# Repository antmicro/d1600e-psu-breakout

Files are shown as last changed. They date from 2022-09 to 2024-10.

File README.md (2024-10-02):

# Antmicro's open source D1600E PSU Breakout Board

Copyright (c) 2022-2023 [Antmicro](https://www.antmicro.com)



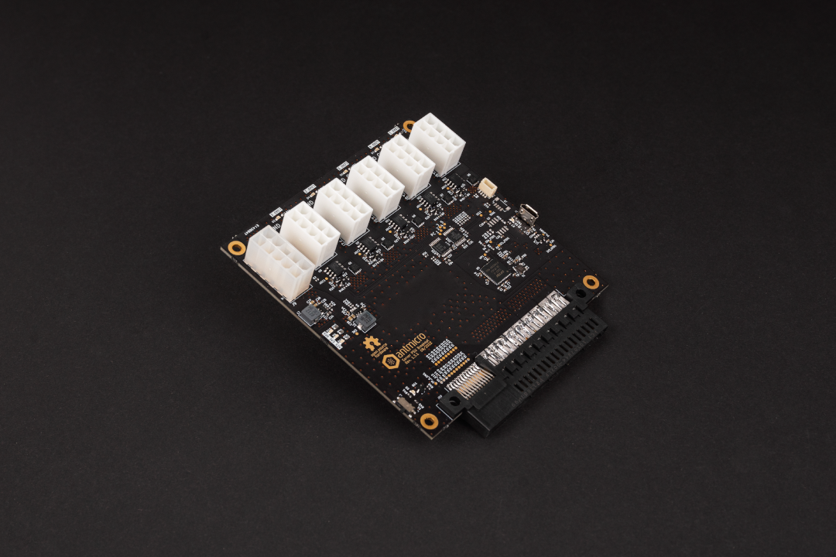
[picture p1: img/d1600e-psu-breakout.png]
Baseboard visualization


## Overview

This project contains open hardware design files for a Power Supply Unit (PSU) breakout board compatible with [Dell D1600E-S0 PSU](https://www.dell.com/en-us/work/shop/dell-power-supply-ac-1600-watt-psu-io/apd/450-ahuc/computer-chassis-components). 
The design files were prepared in KiCad.

### Project structure:

The main directory contains the KiCad design files, LICENSE and README.
The remaining files are stored in the following directories:

* ``img`` - contains graphics for this README
* ``doc`` - contains generated schematics and other documentation
* ``assets`` - contains visual assets for showcasing this design on [Open Hardware Portal](https://openhardware.antmicro.com/boards/d1600e-psu-breakout) and [Antmicro Designer](https://designer.antmicro.com/hardware/devices/d1600e-psu-breakout).

## Key features

* 5x power output channels providing 12V over 8-pin PCI Express type (Molex/39288080) sockets
* Up to 220W per single 12V power output channel
* Output current measurement implemented with [Ti/TMCS1100A2QDRQ1](https://www.ti.com/lit/ds/symlink/tmcs1100-q1.pdf) Hall sensors and 12-bit [Ti/ADS7828E](https://www.ti.com/lit/ds/symlink/ads7828.pdf) ADC accessible over I2C
* Power-cycling for each channel implemented with power MOSFETS driven from [Ti/TCA9534](https://www.ti.com/lit/ds/symlink/tca9534.pdf) GPIO expander accessible over I2C 
* I2C bus for current measurements and power cycling is opto-coupled with [FTDI/FT4232H-56Q](https://www.ftdichip.com/Support/Documents/DataSheets/ICs/DS_FT4232H.pdf) with USB exposed towards an external host
* Auxilary connector (Molex/39281103) exposing 5.0V,3.3V,12V for connecting external peripherals

## License

This project is published under the [Apache-2.0](LICENSE) license.

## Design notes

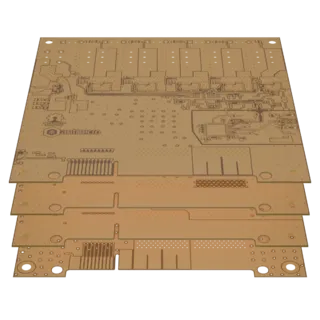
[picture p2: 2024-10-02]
assets/previews/layer1_thumbnail.webp

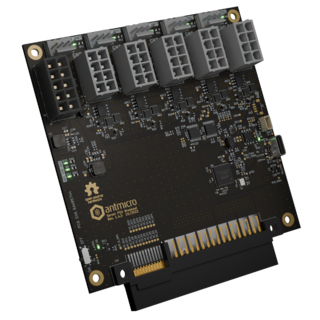
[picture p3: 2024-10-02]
assets/previews/leftT_thumbnail.png

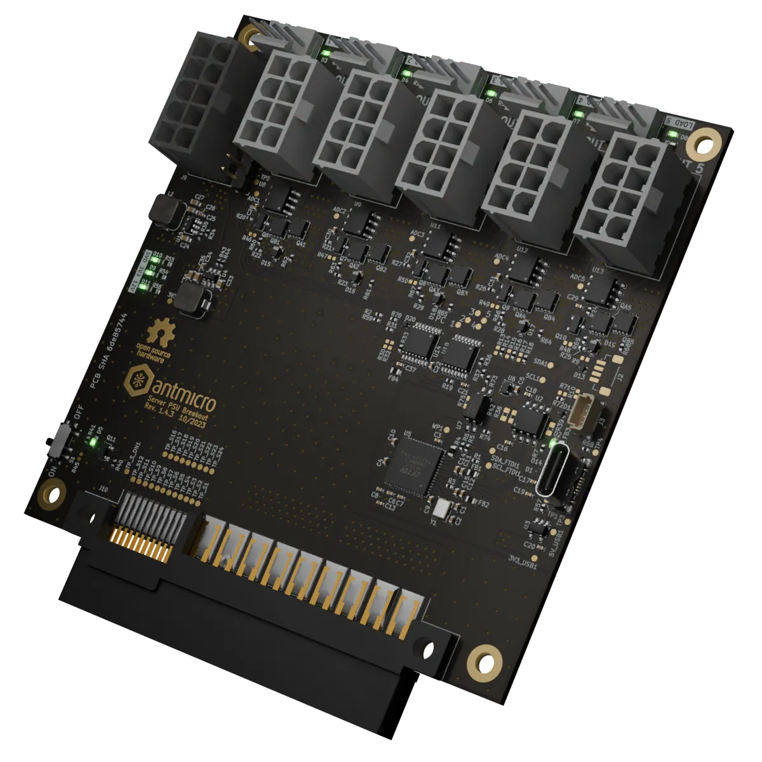
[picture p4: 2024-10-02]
assets/previews/rightT.webp

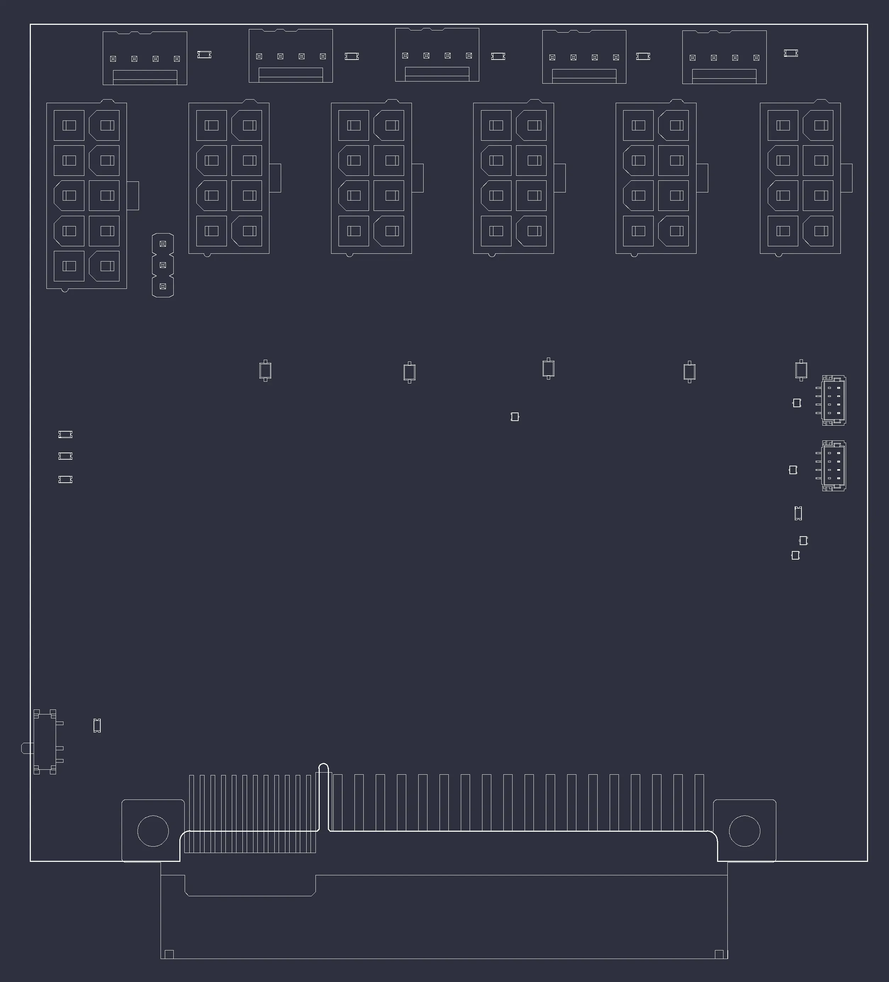
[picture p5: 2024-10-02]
assets/wireframe/wireframe_descriptions_top.webp

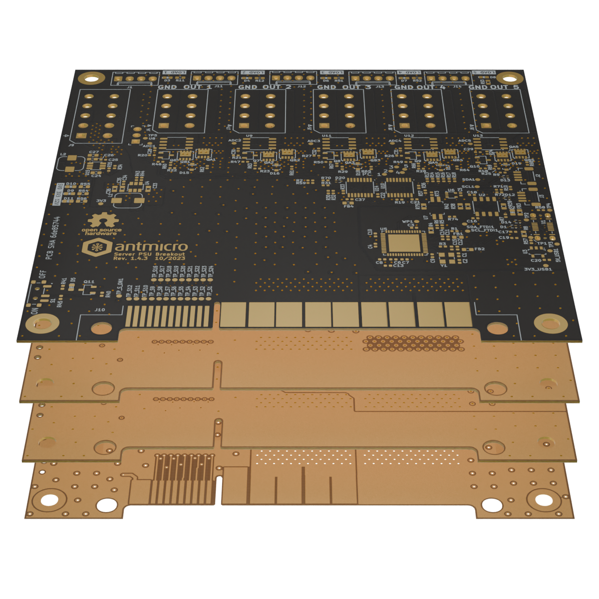
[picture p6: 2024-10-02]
assets/previews/stackup.png

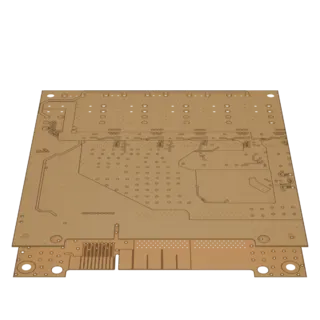
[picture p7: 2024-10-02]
assets/previews/layer3_thumbnail.webp

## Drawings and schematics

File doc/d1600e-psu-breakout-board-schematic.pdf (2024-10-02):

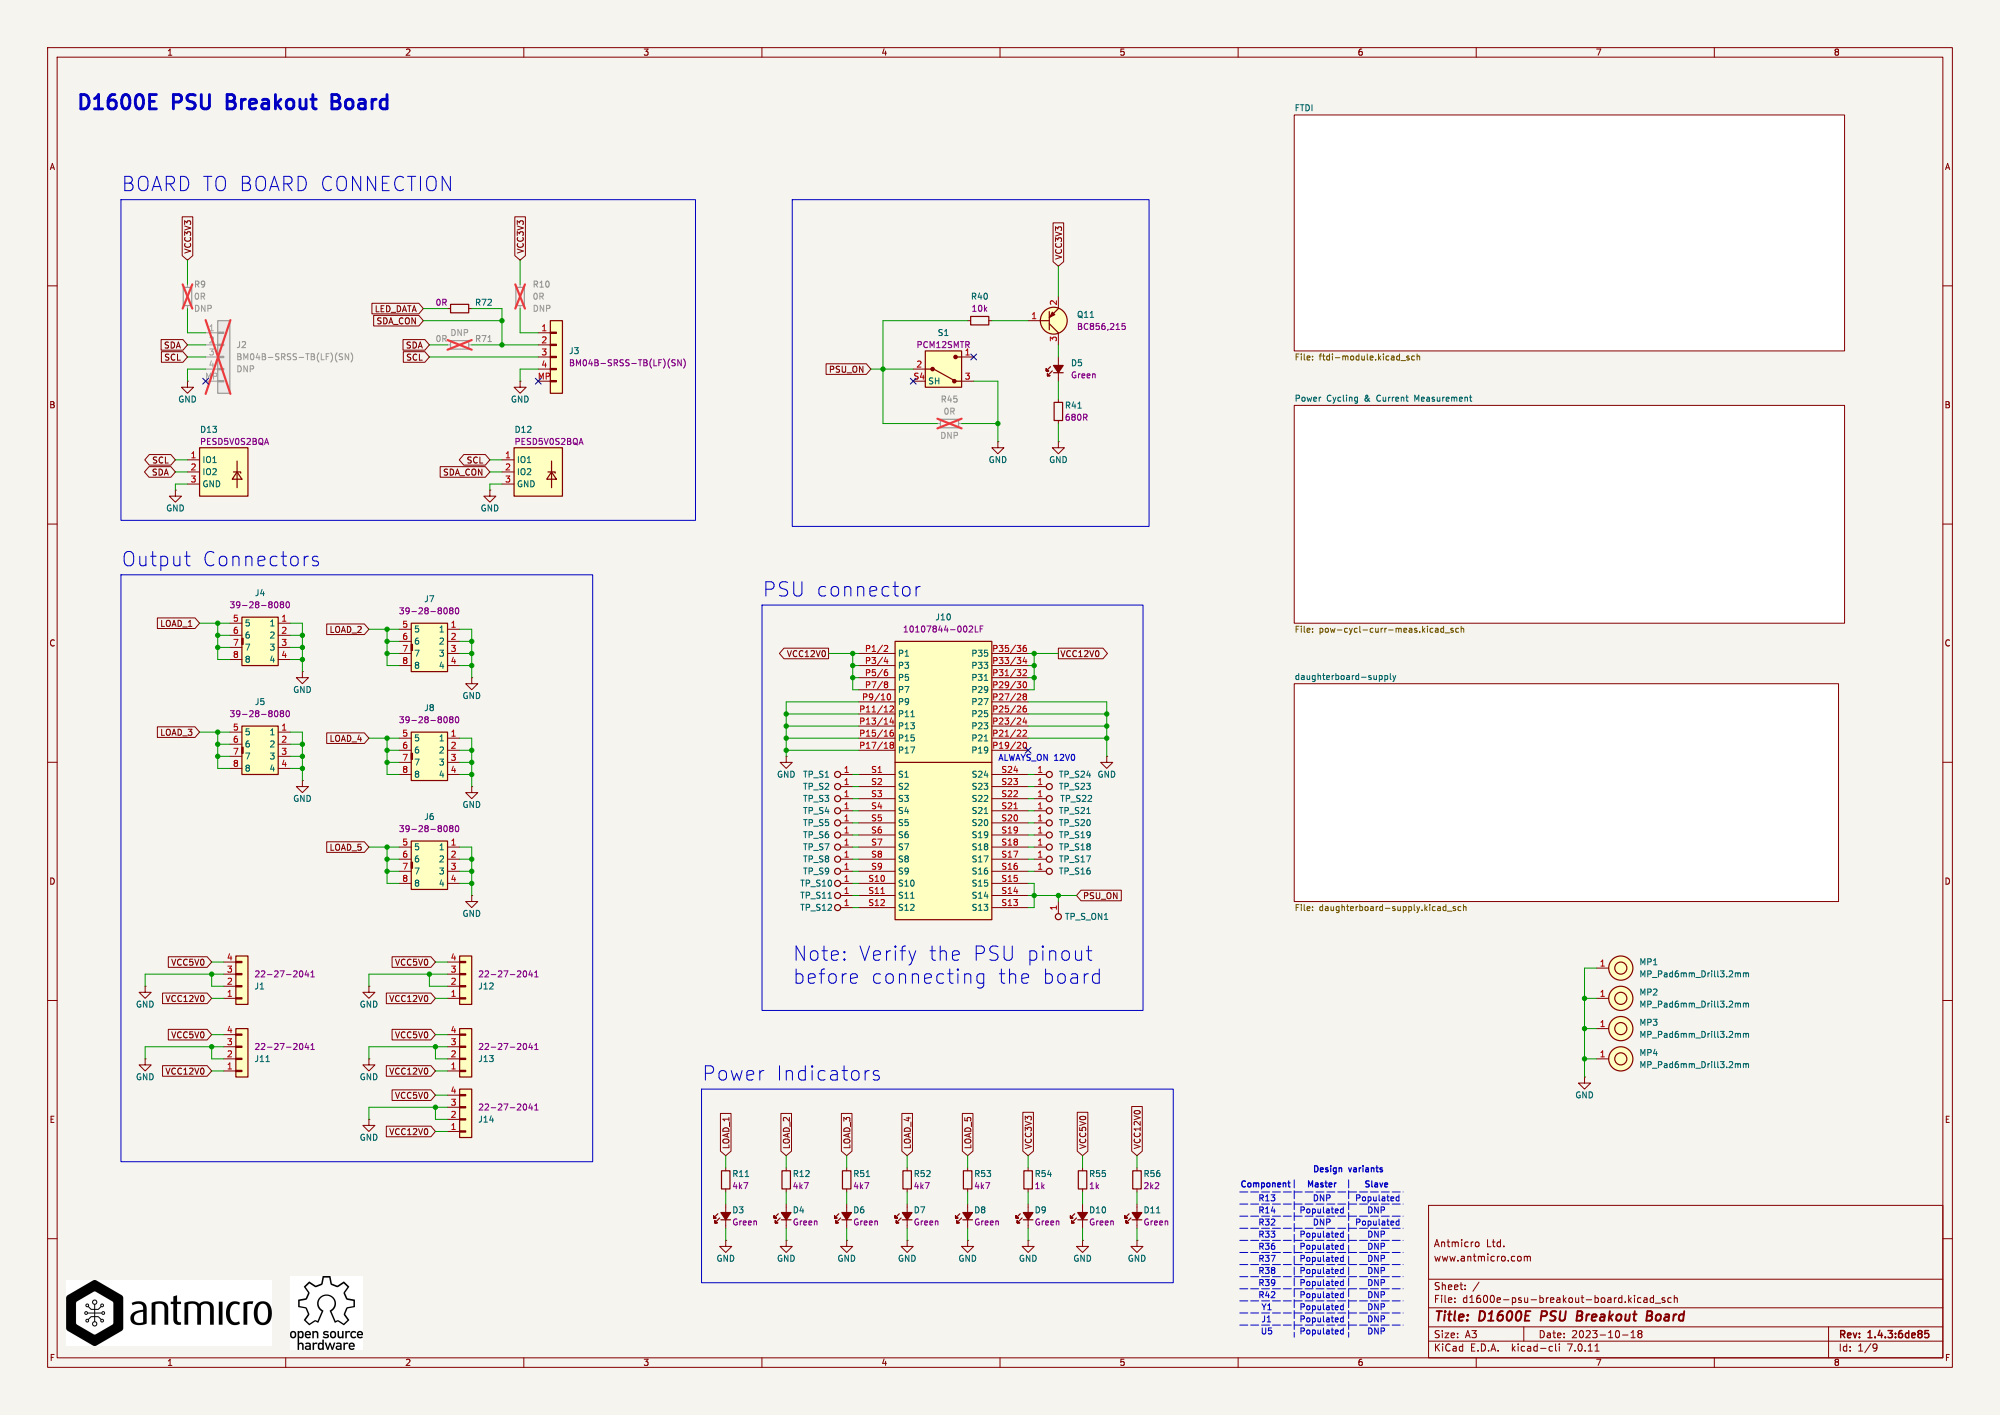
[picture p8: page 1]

FTDI File: ftdi-module.kicad_sch Power Cycling & Current Measurement File: pow-cycl-curr-meas.kicad_sch R41

ALWAYS_ON 12V0 BOARD TO BOARD CONNECTION

daughterboard-supply File: daughterboard-supply.kicad_sch

Note: Verify the PSU pinout

File: d1600e-psu-breakout-board.kicad_sch Sheet: / www.antmicro.com

Id: 1/9 Title: D1600E PSU Breakout Board

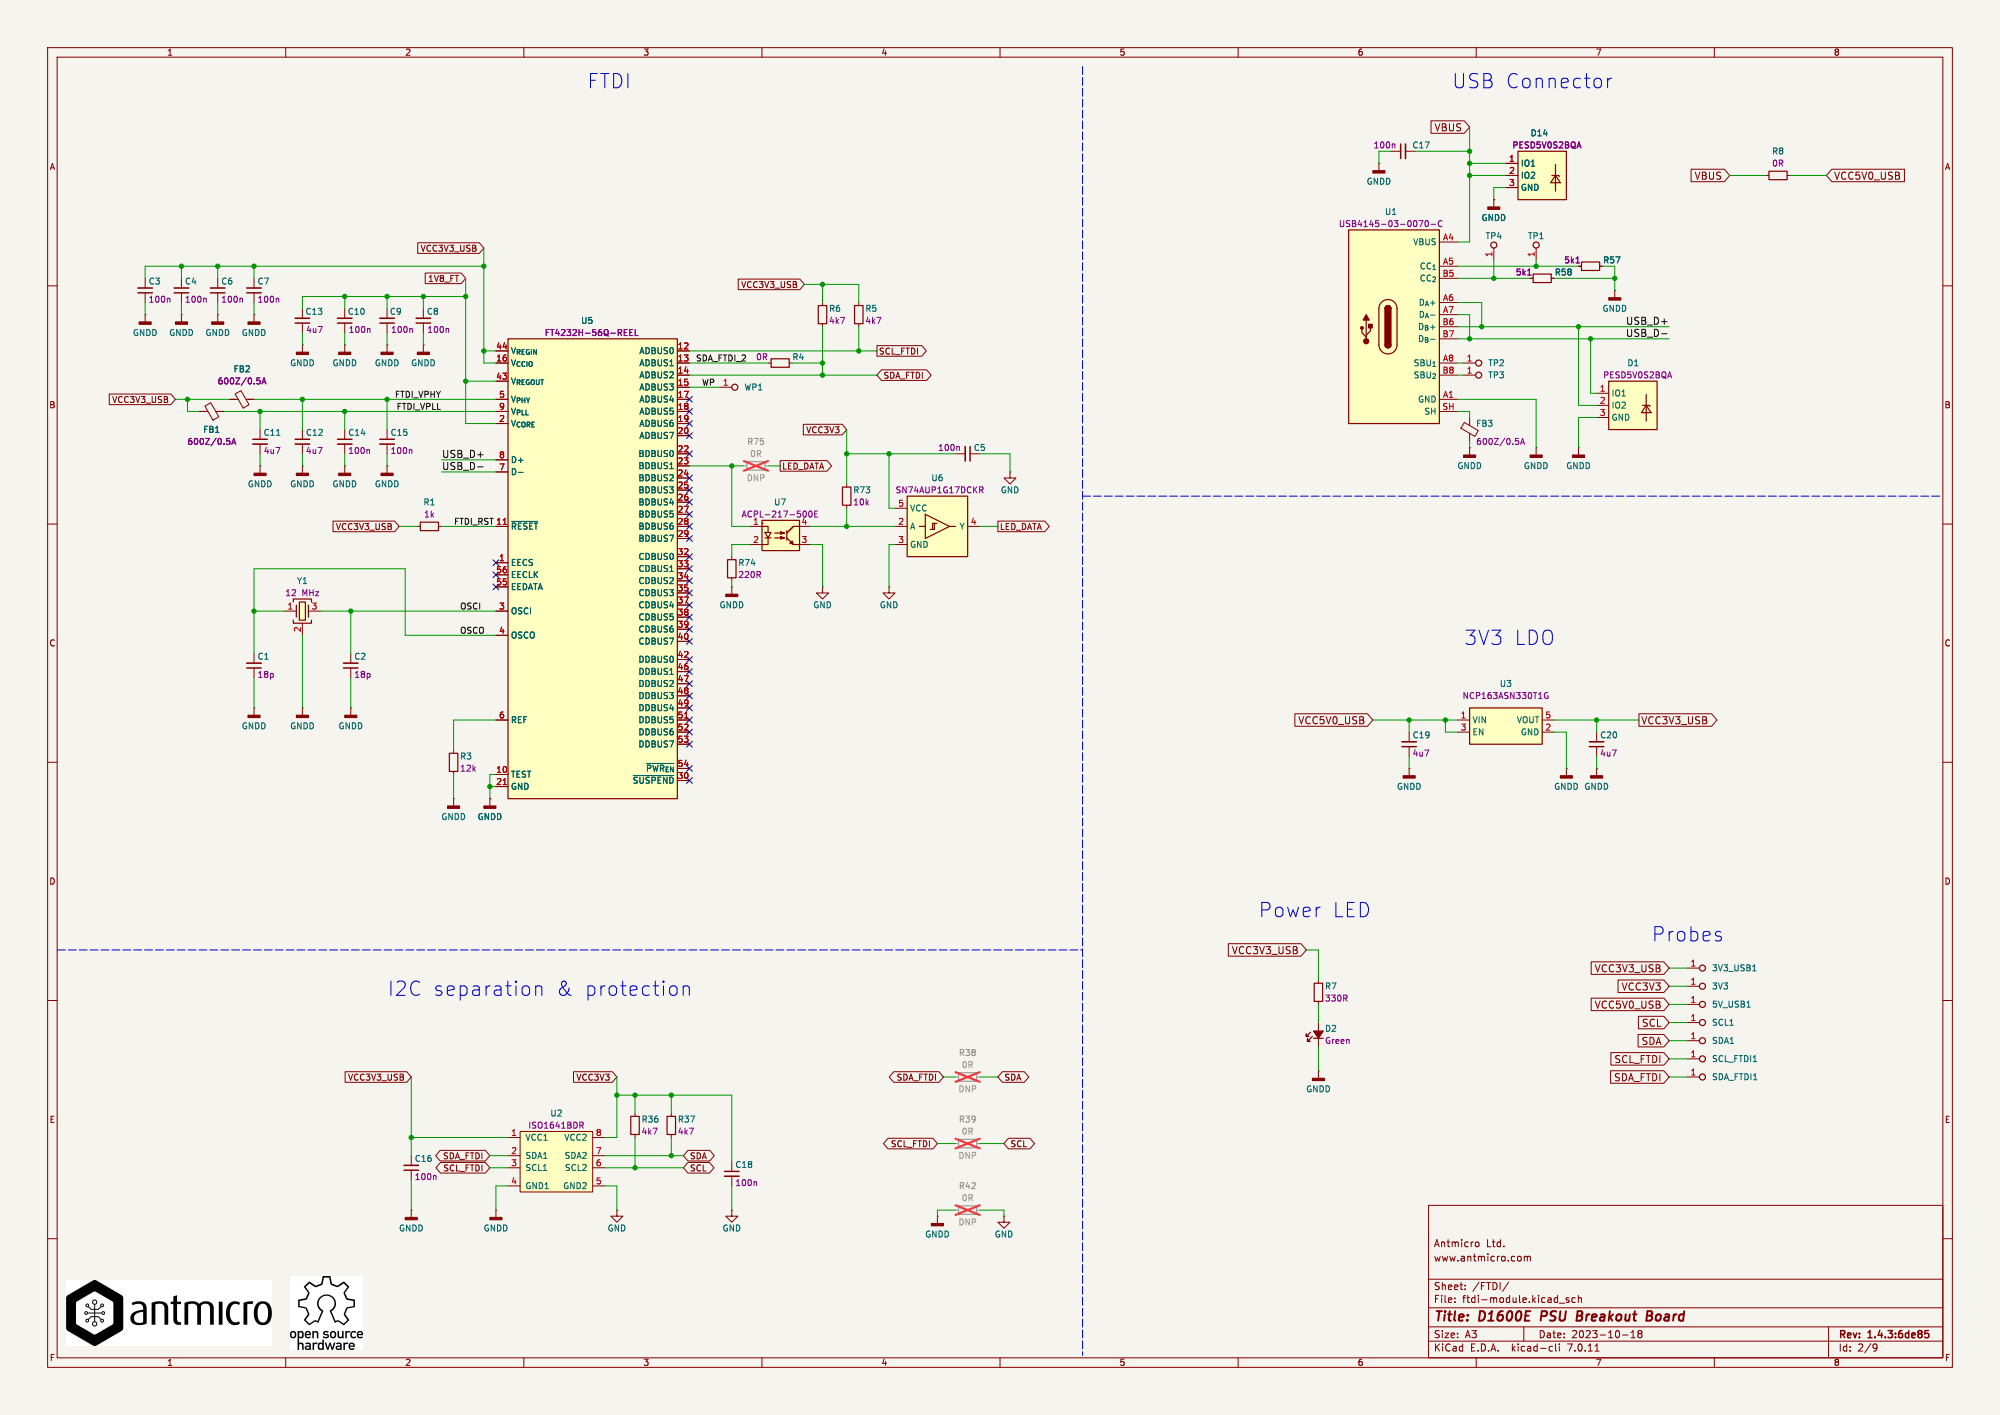
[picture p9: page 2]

File: ftdi-module.kicad_sch Sheet: /FTDI/ www.antmicro.com

Id: 2/9 Title: D1600E PSU Breakout Board

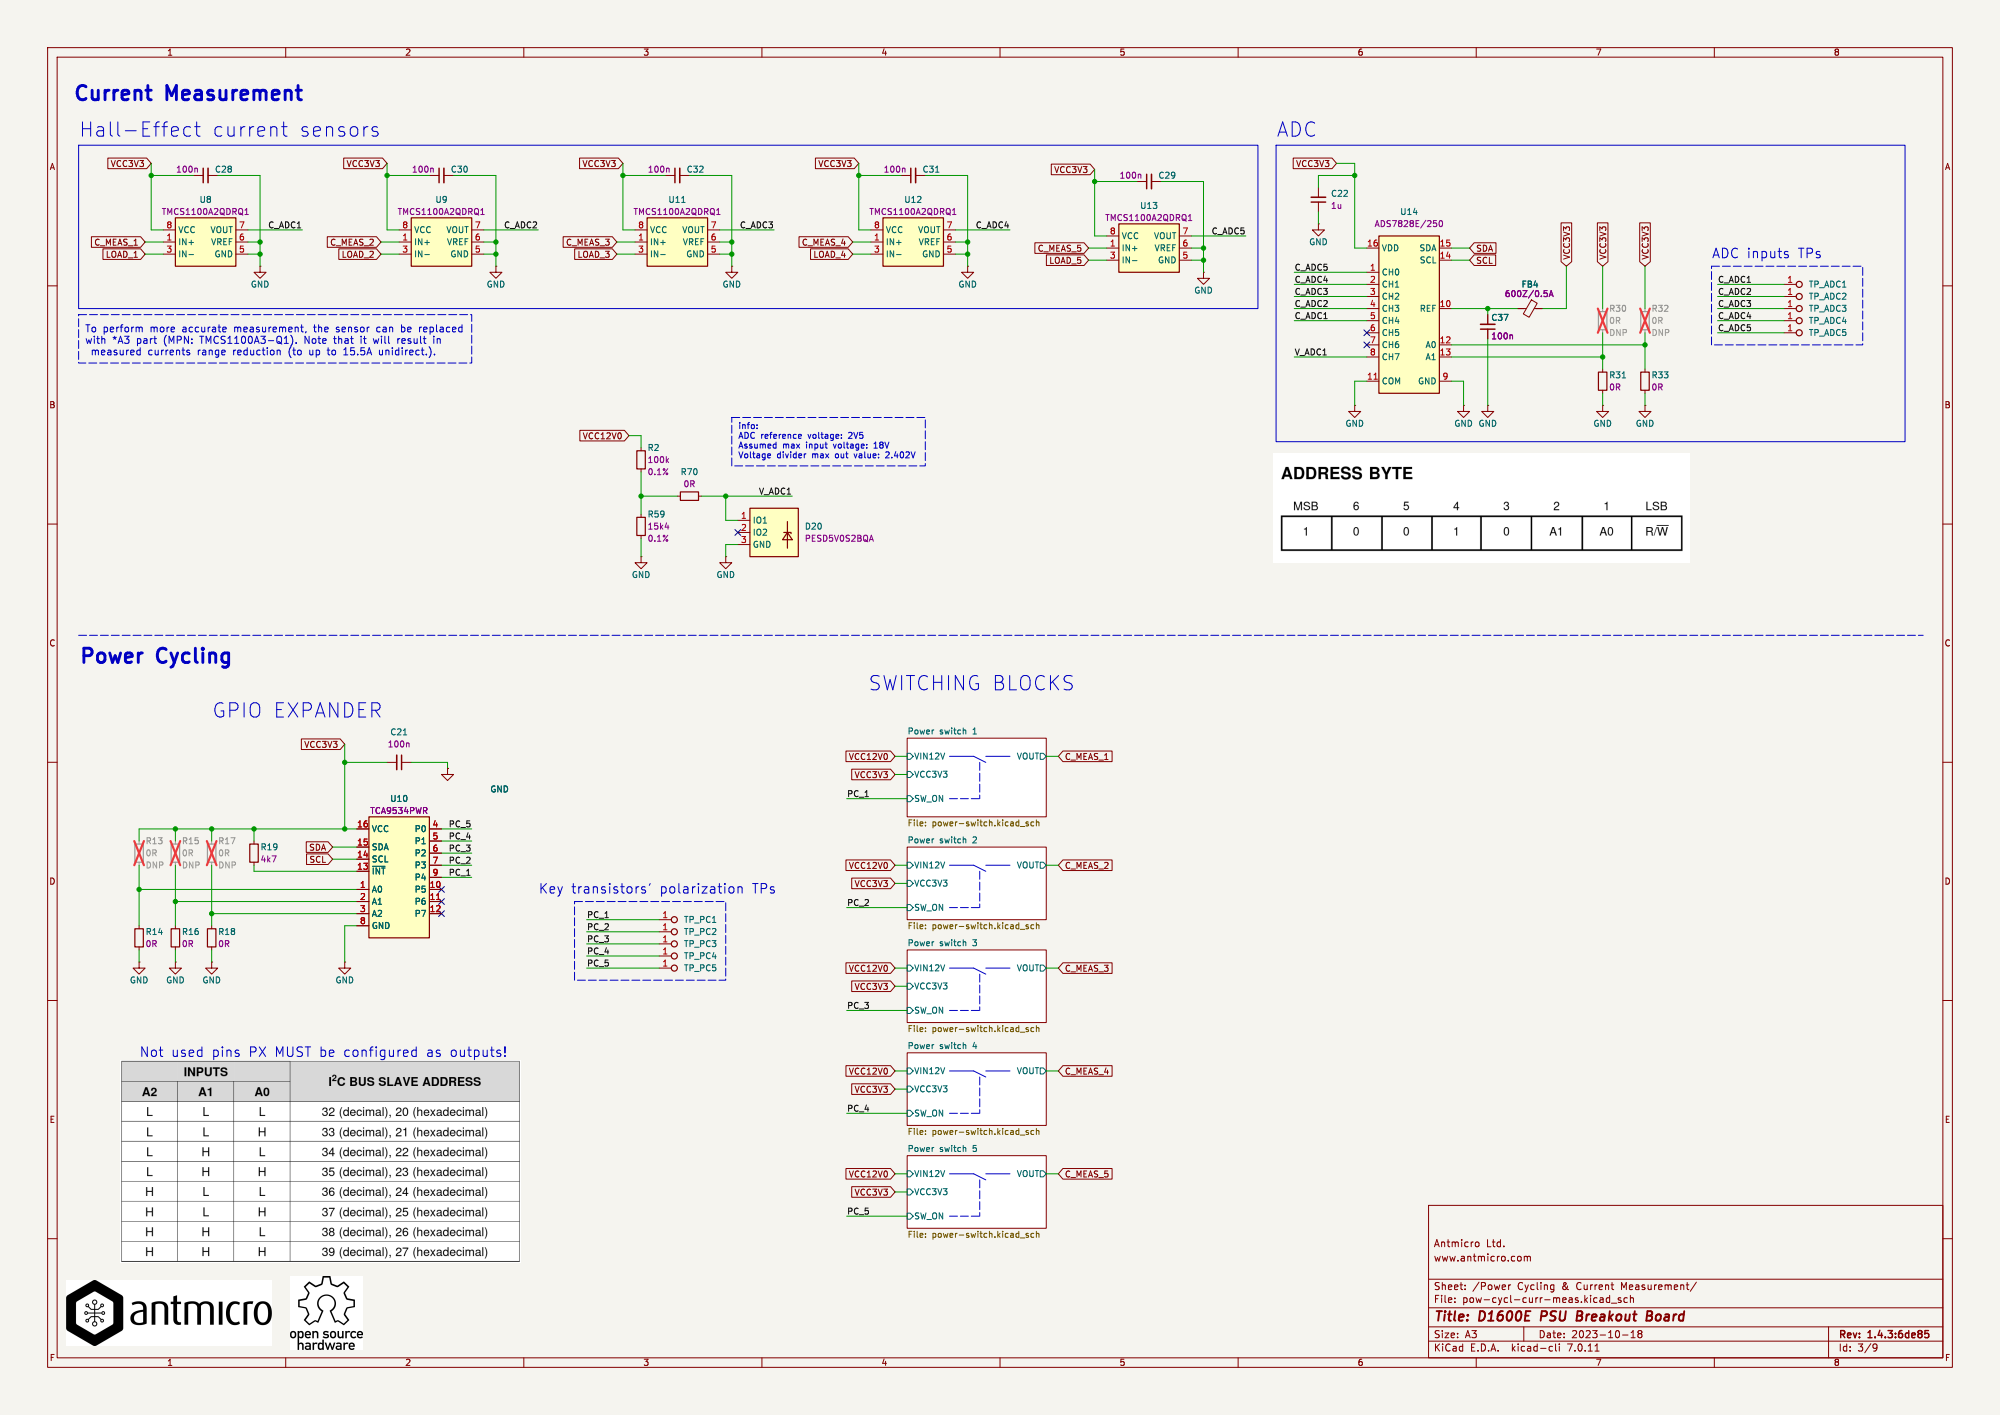
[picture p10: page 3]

Id: 3/9 Title: D1600E PSU Breakout Board

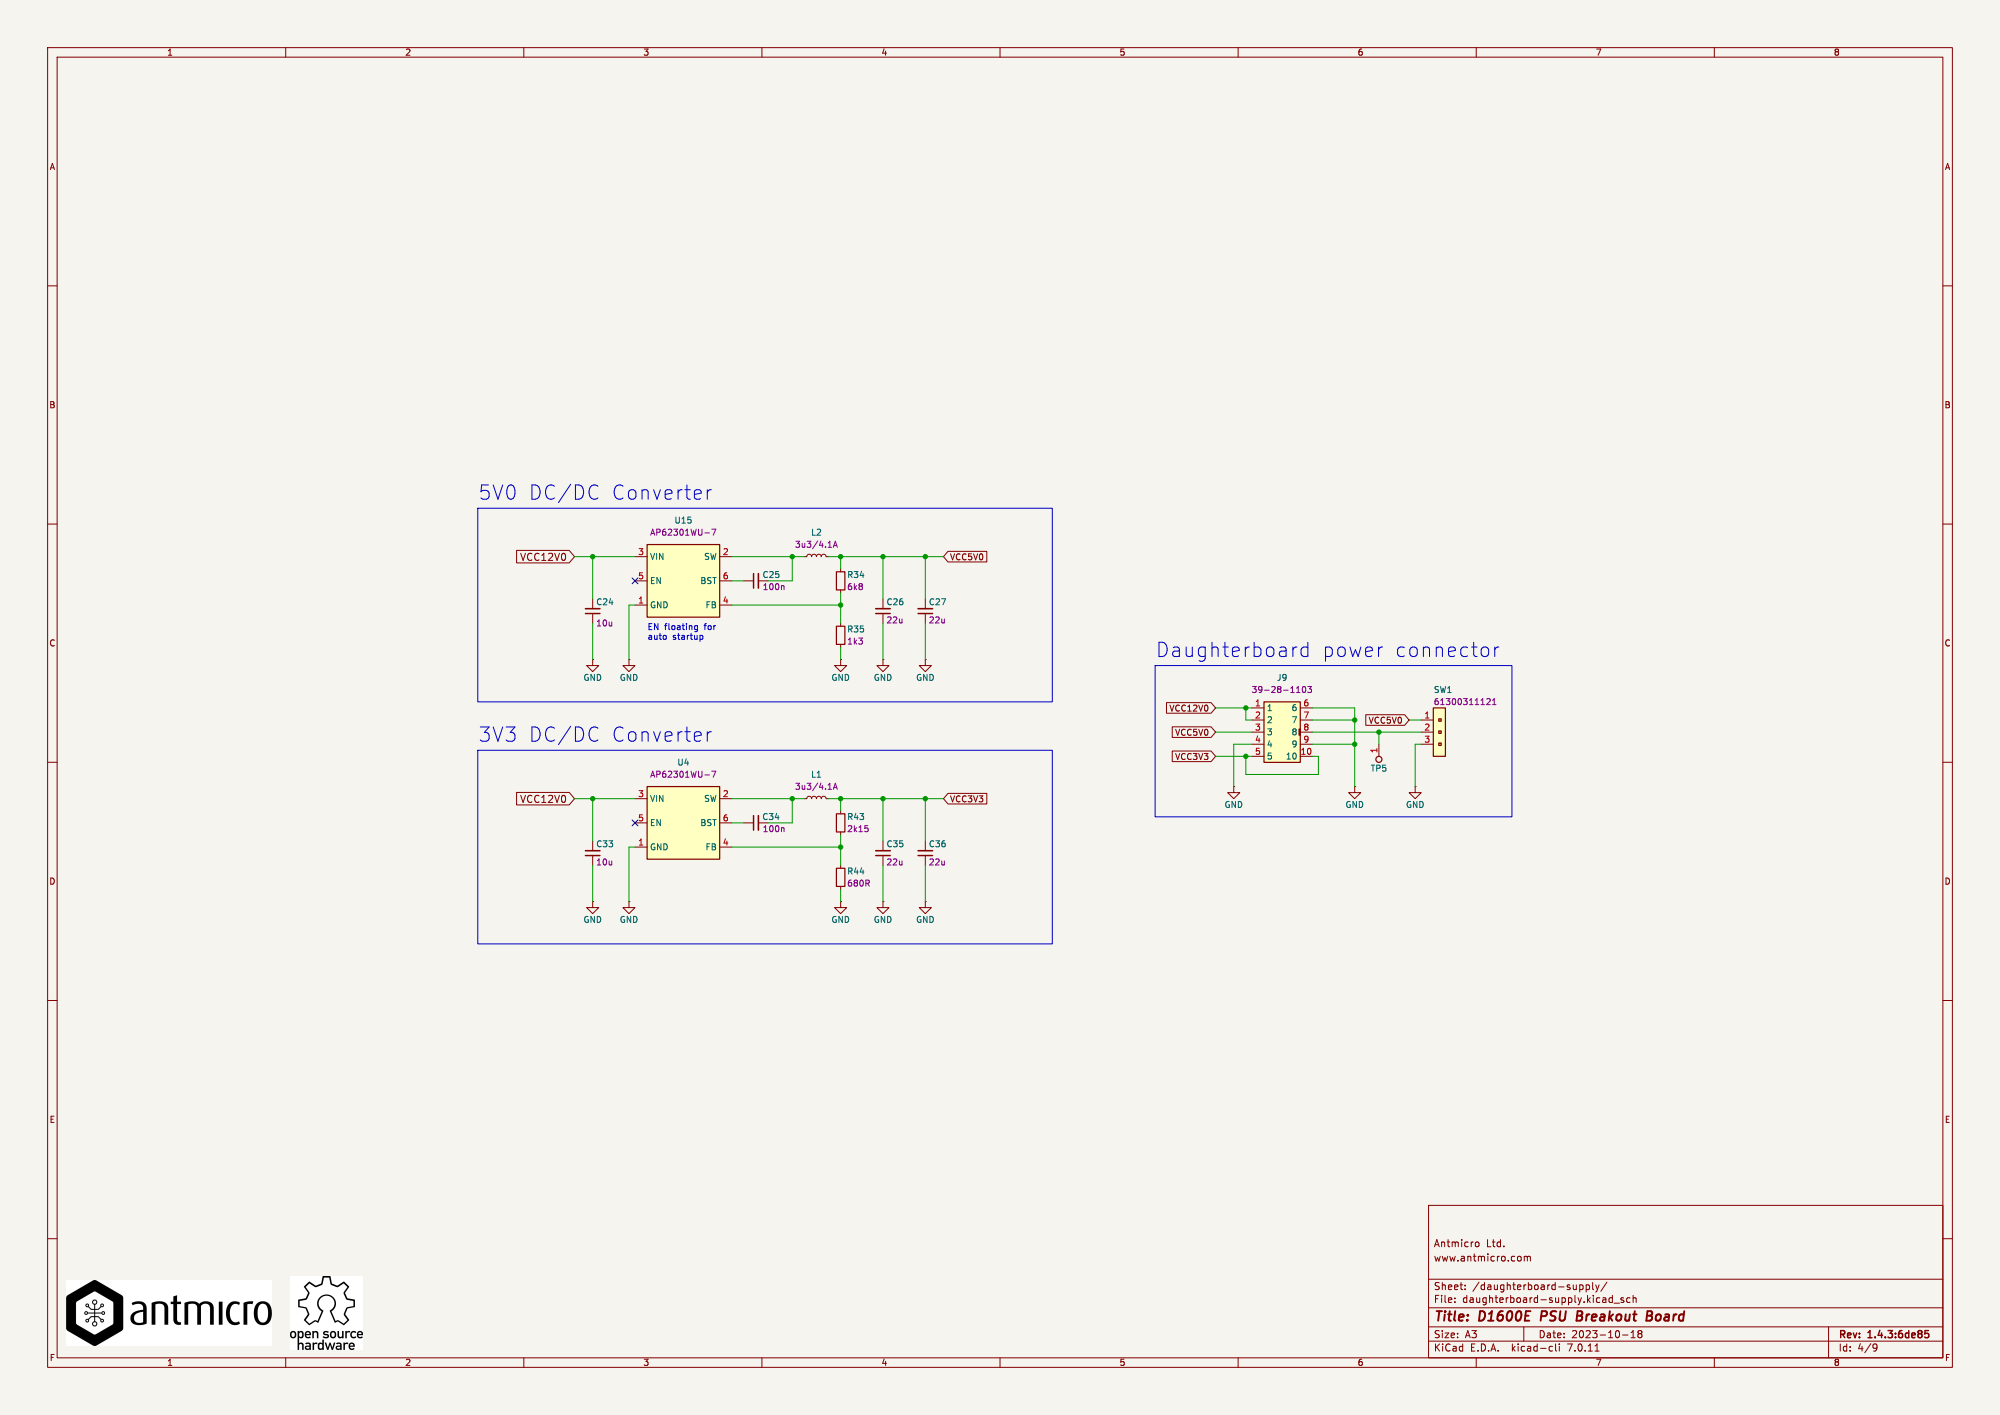
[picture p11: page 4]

File: daughterboard-supply.kicad_sch Sheet: /daughterboard-supply/ www.antmicro.com

Id: 4/9 Title: D1600E PSU Breakout Board

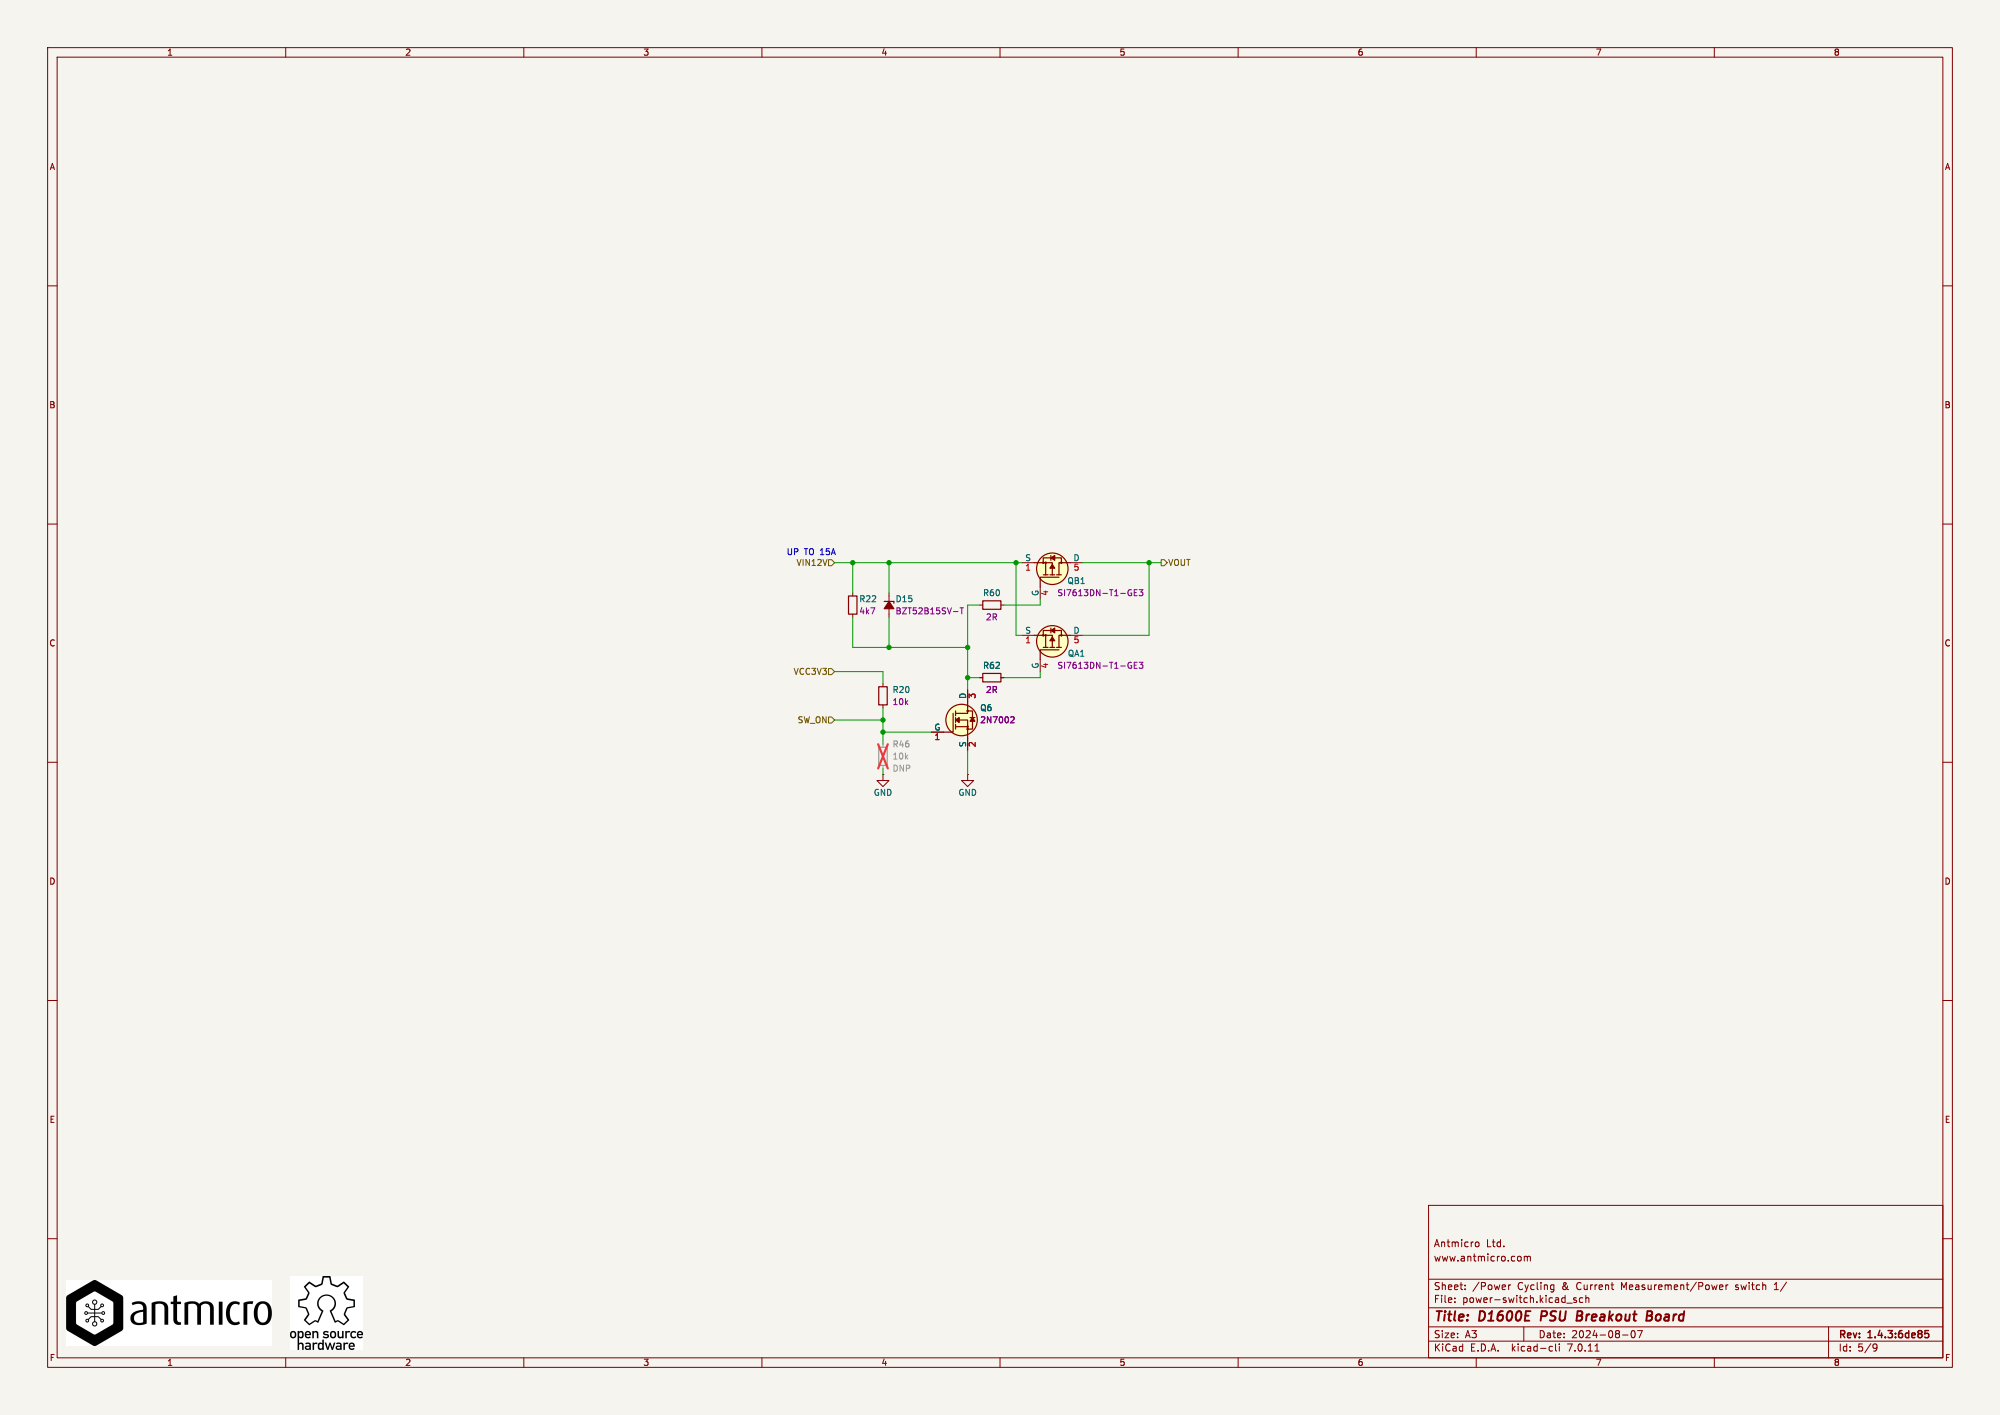
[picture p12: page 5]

Id: 5/9 Title: D1600E PSU Breakout Board

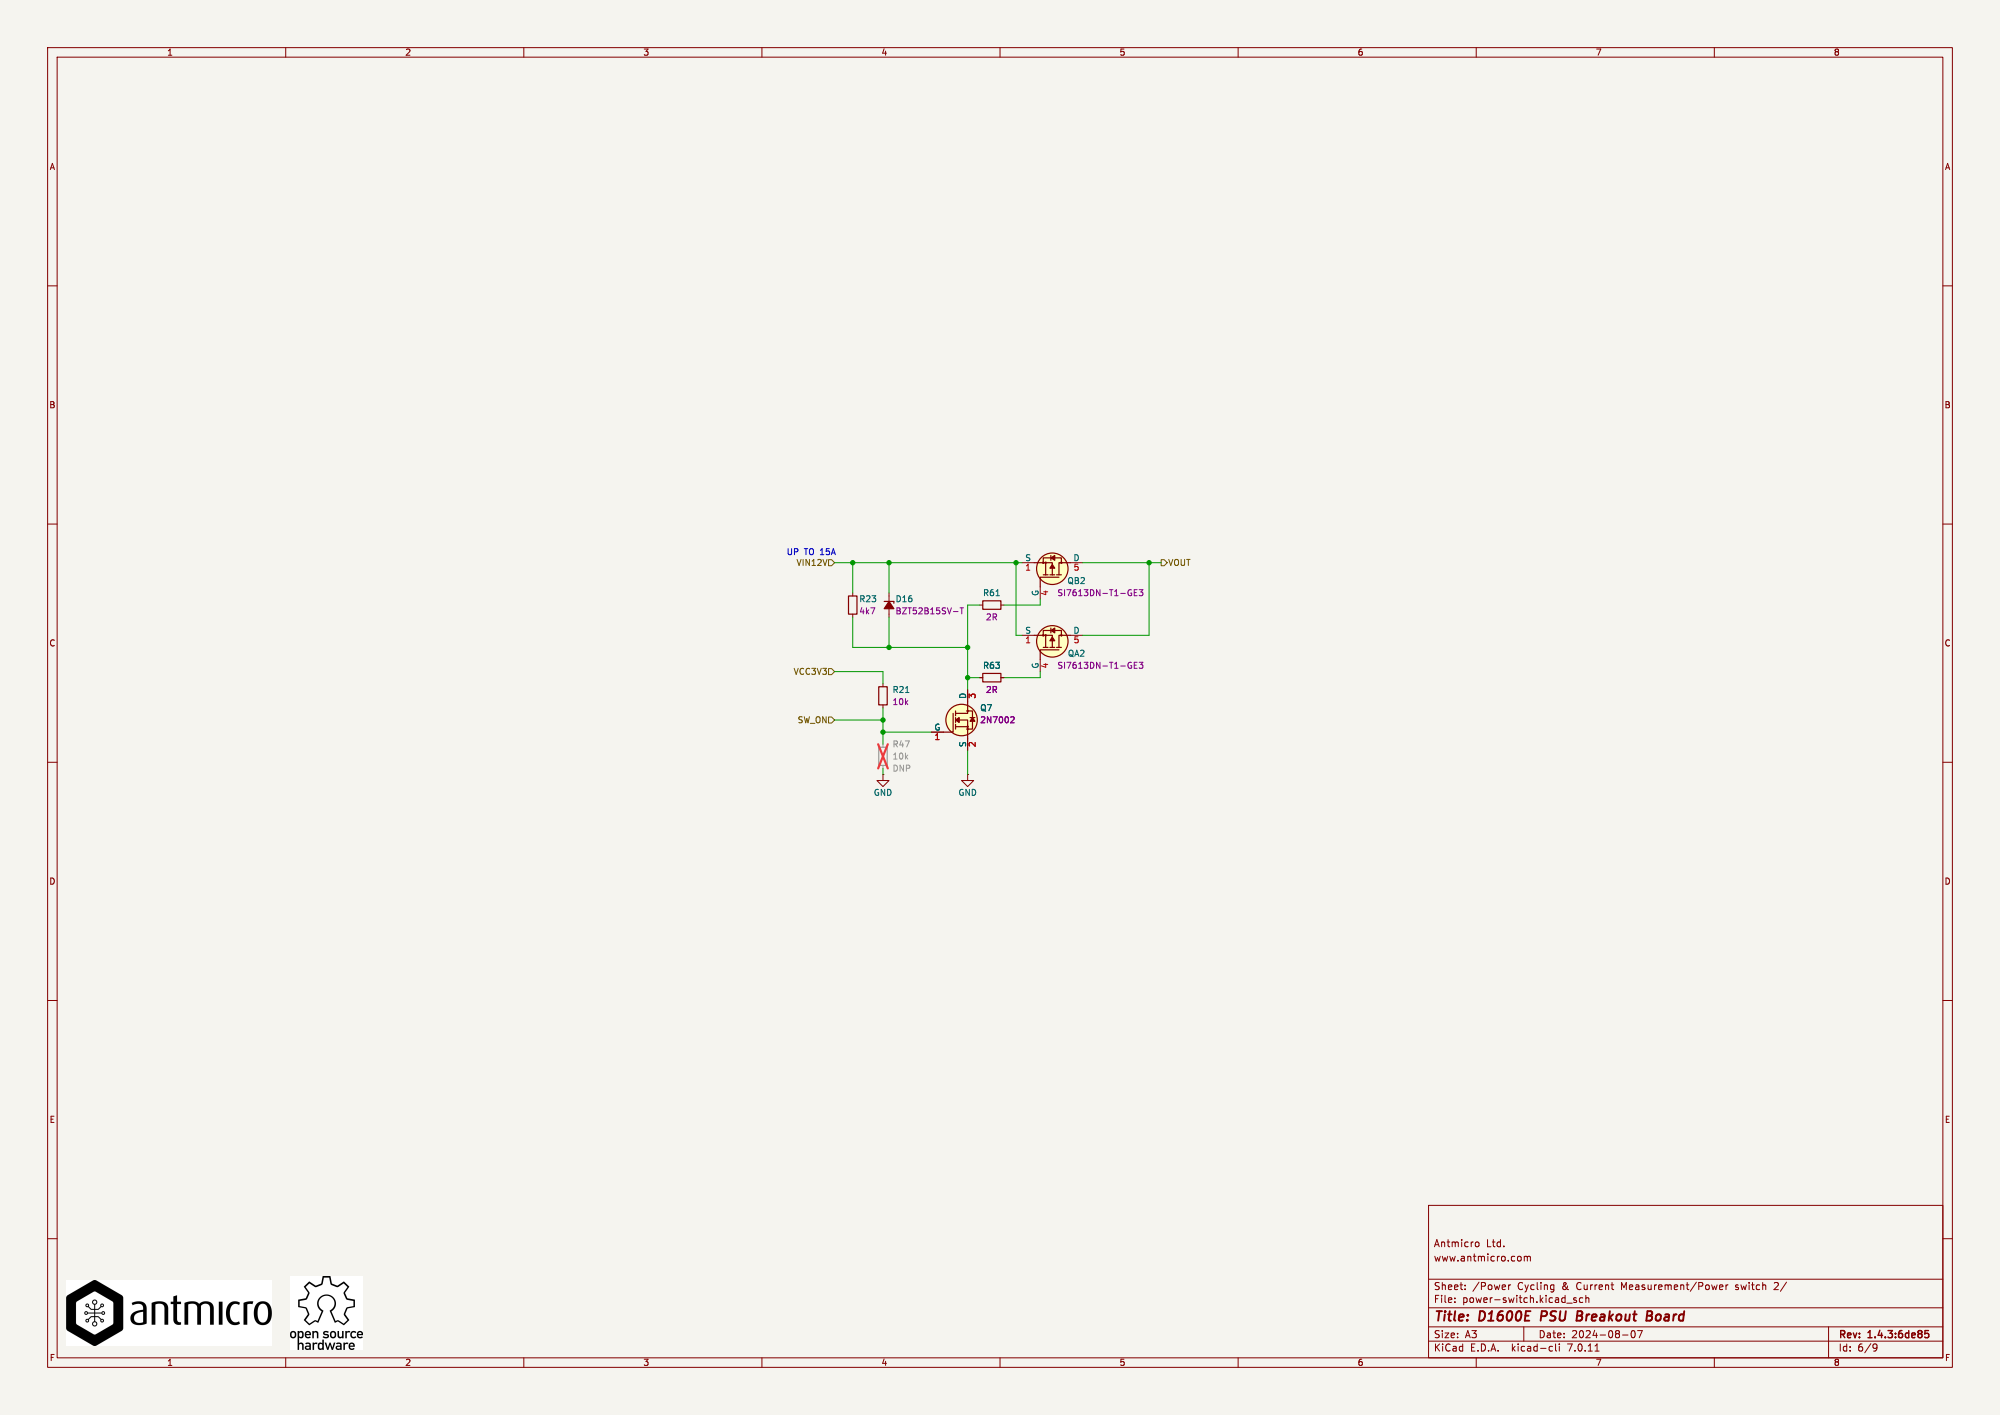
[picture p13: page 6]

Id: 6/9 Title: D1600E PSU Breakout Board

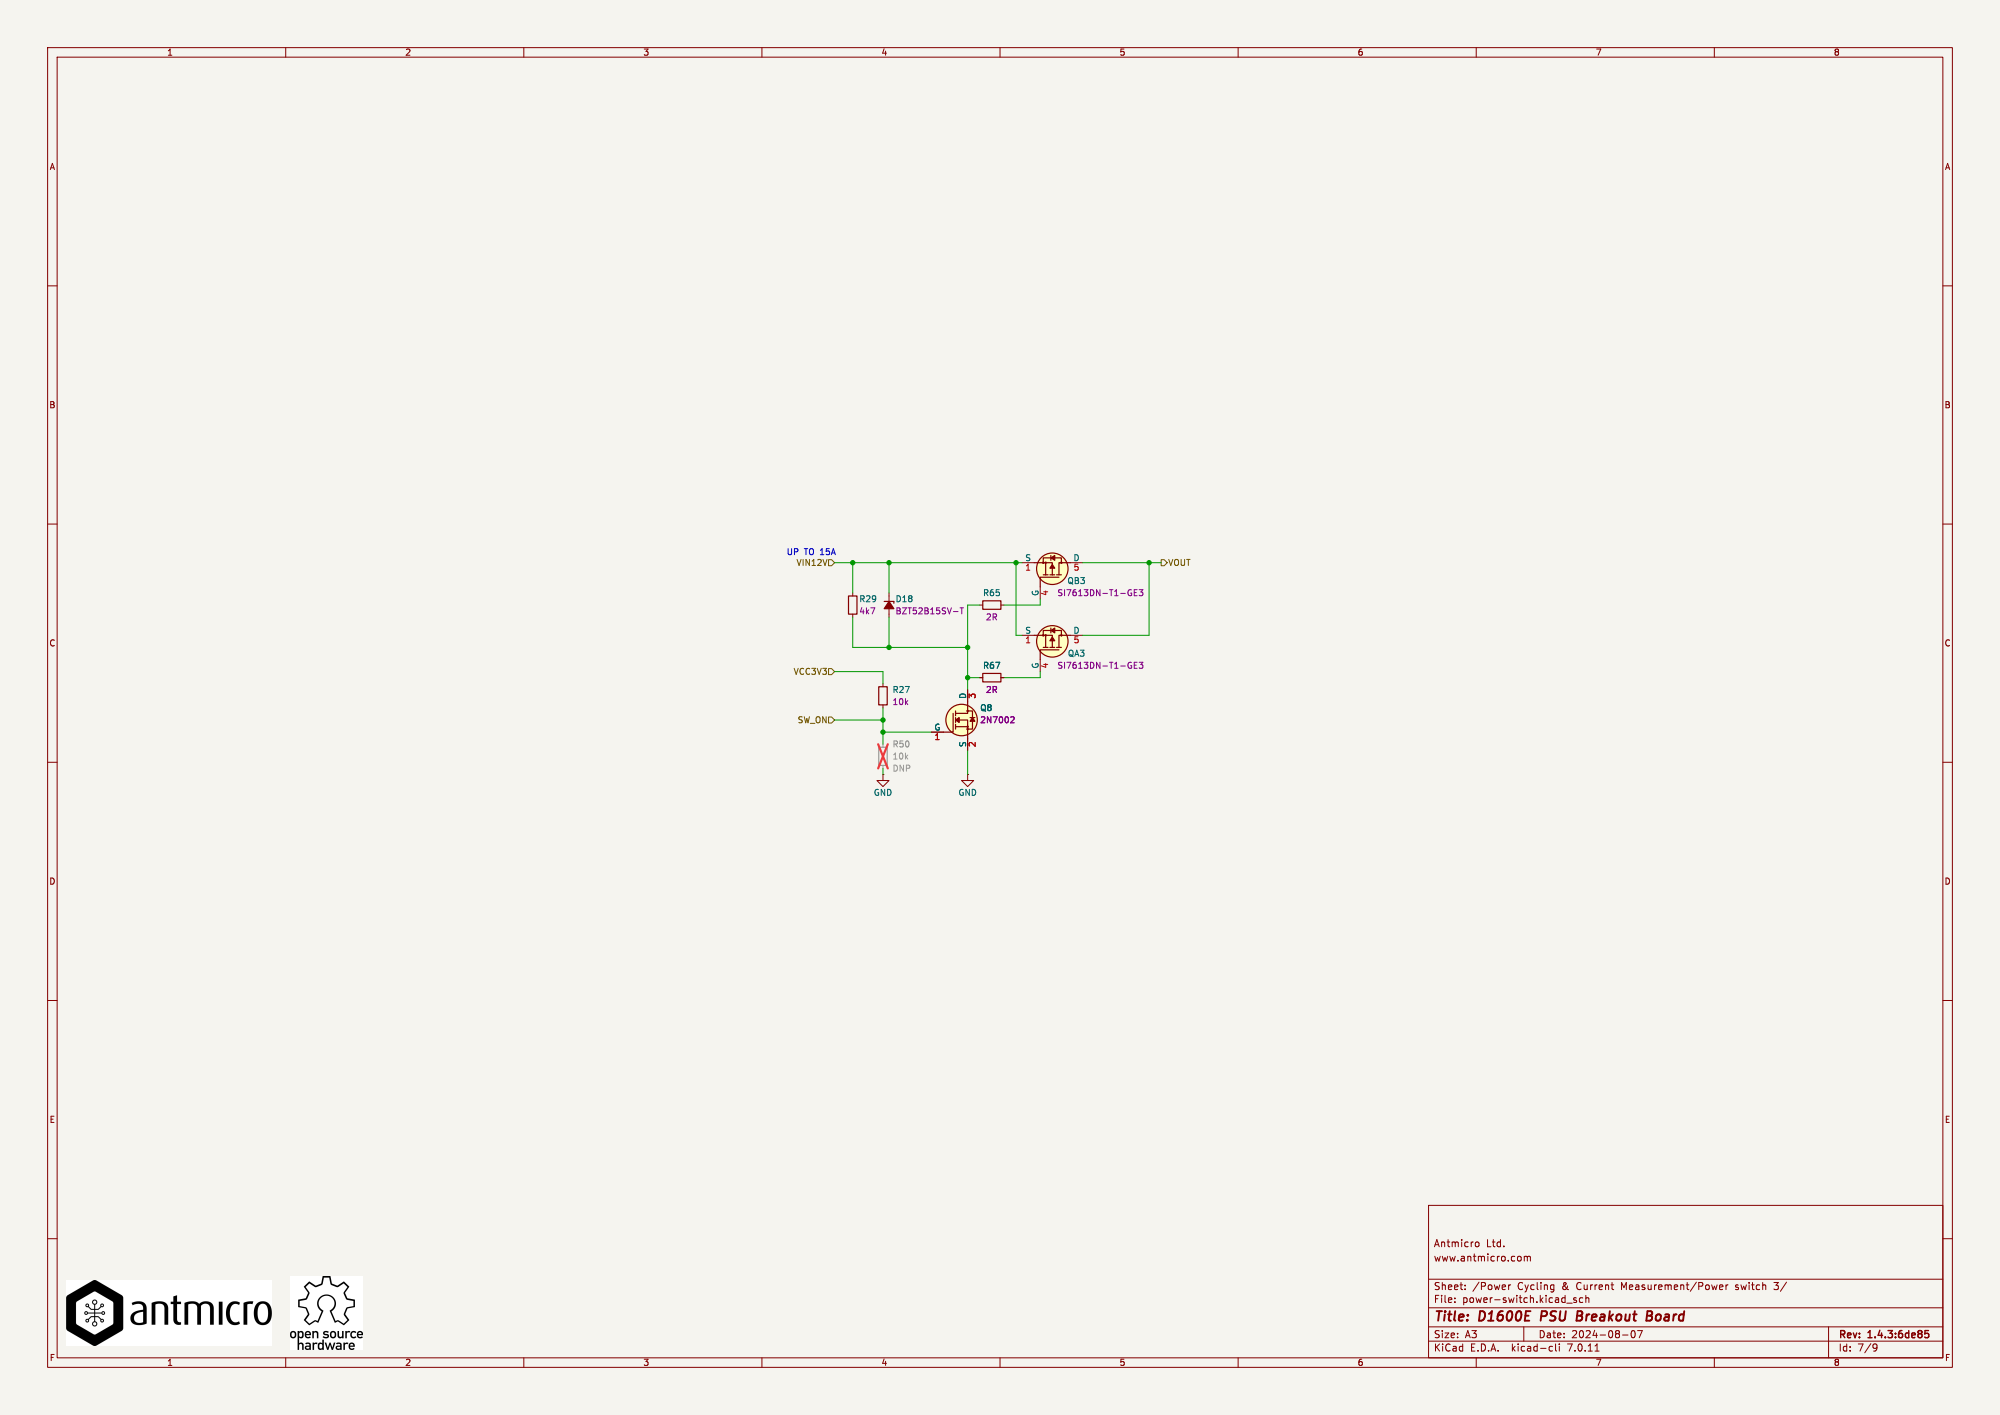
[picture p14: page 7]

Id: 7/9 Title: D1600E PSU Breakout Board

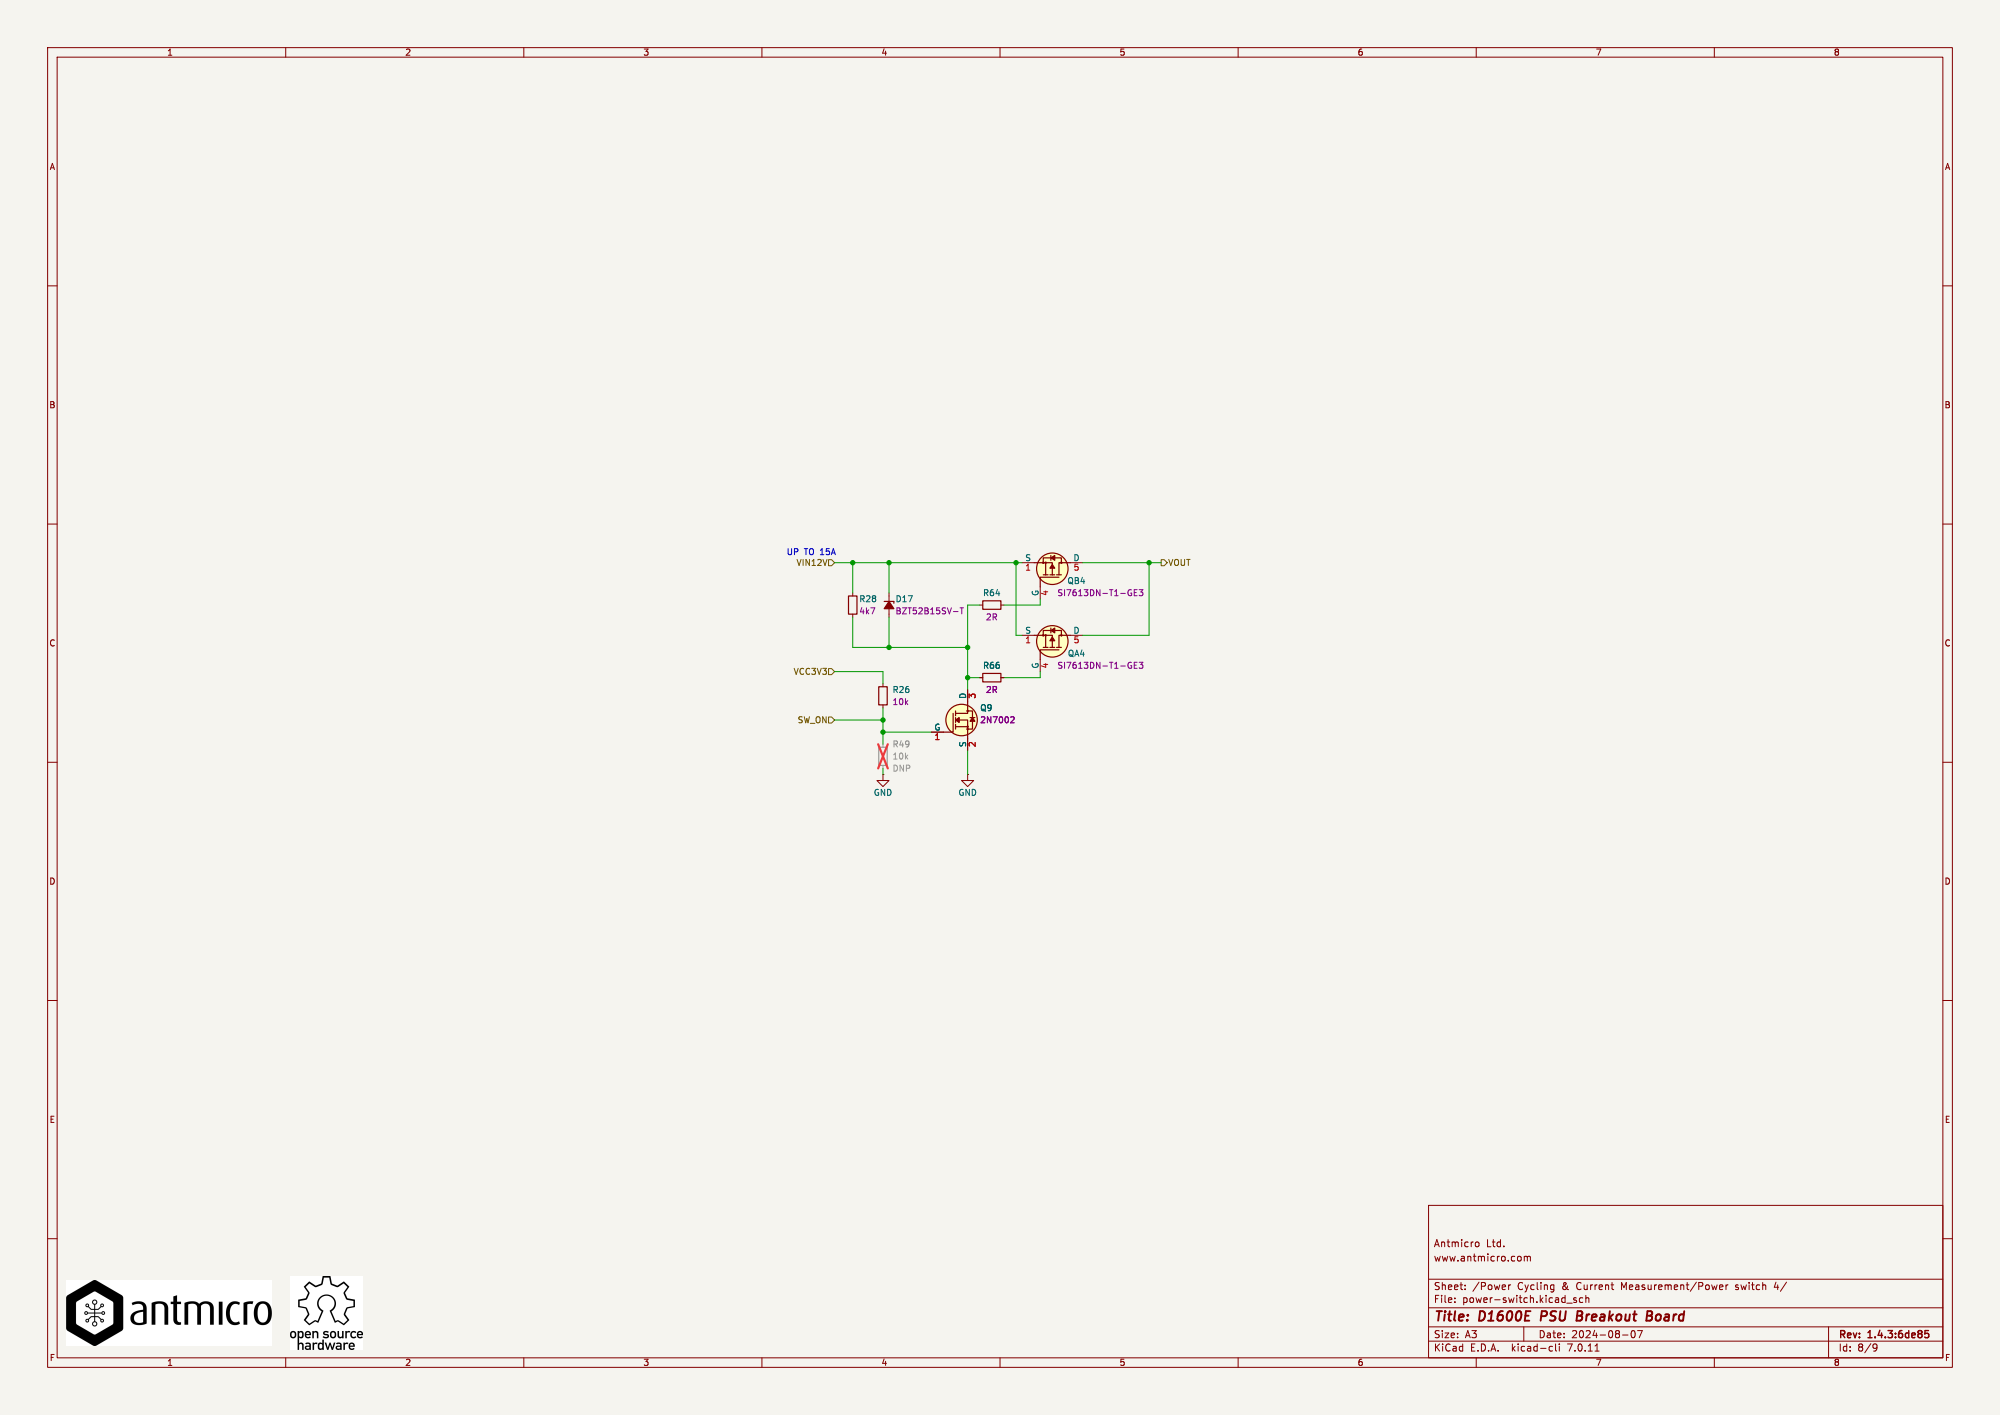
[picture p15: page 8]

Id: 8/9 Title: D1600E PSU Breakout Board

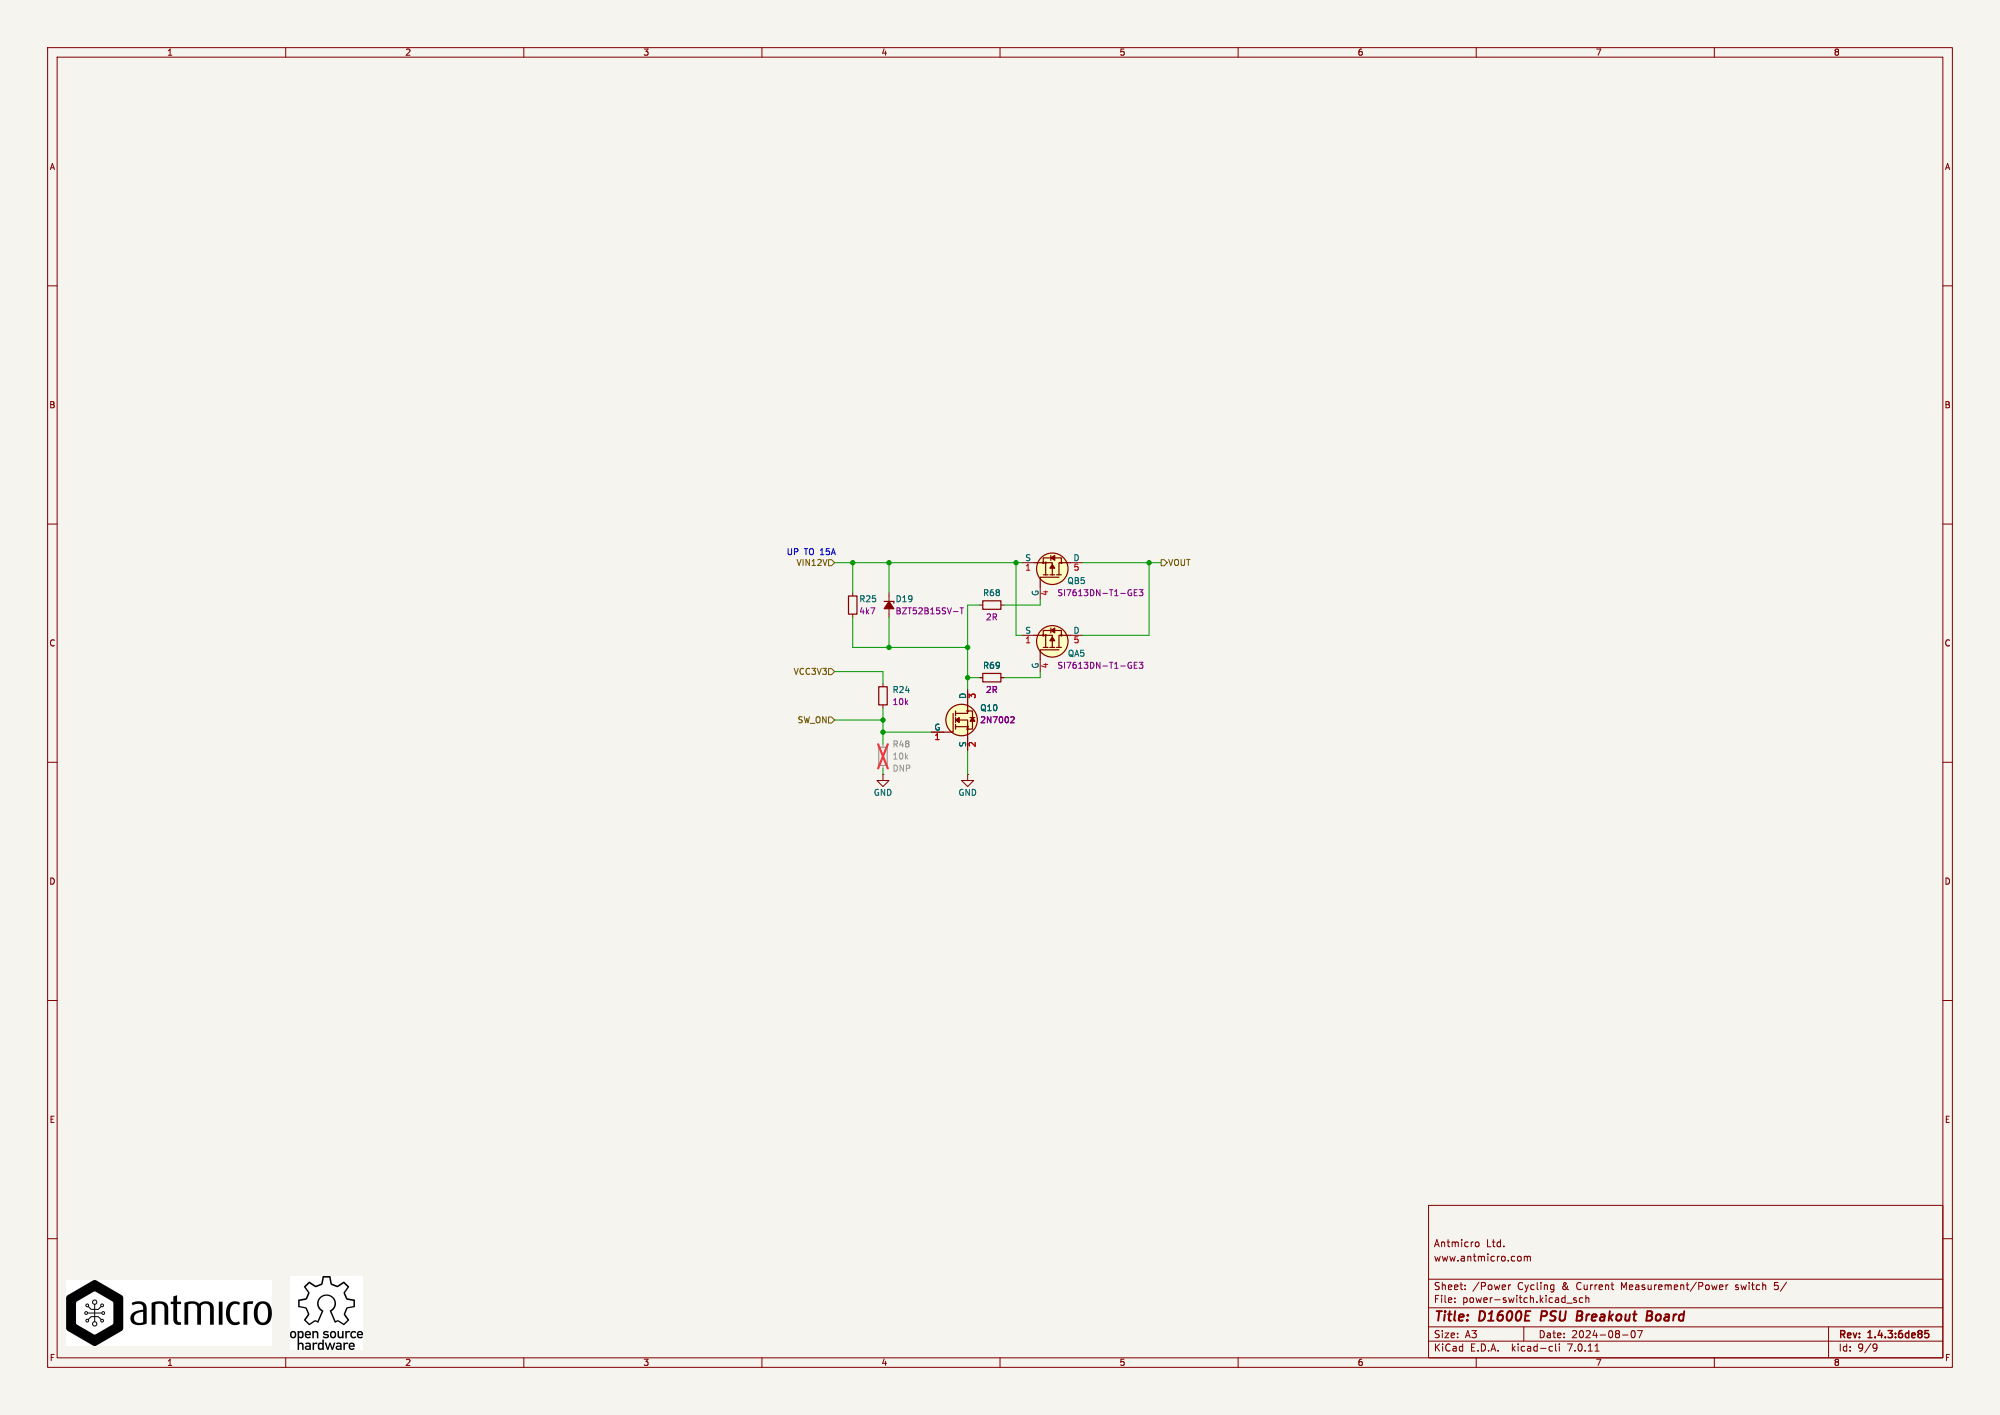
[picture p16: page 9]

Id: 9/9 Title: D1600E PSU Breakout Board

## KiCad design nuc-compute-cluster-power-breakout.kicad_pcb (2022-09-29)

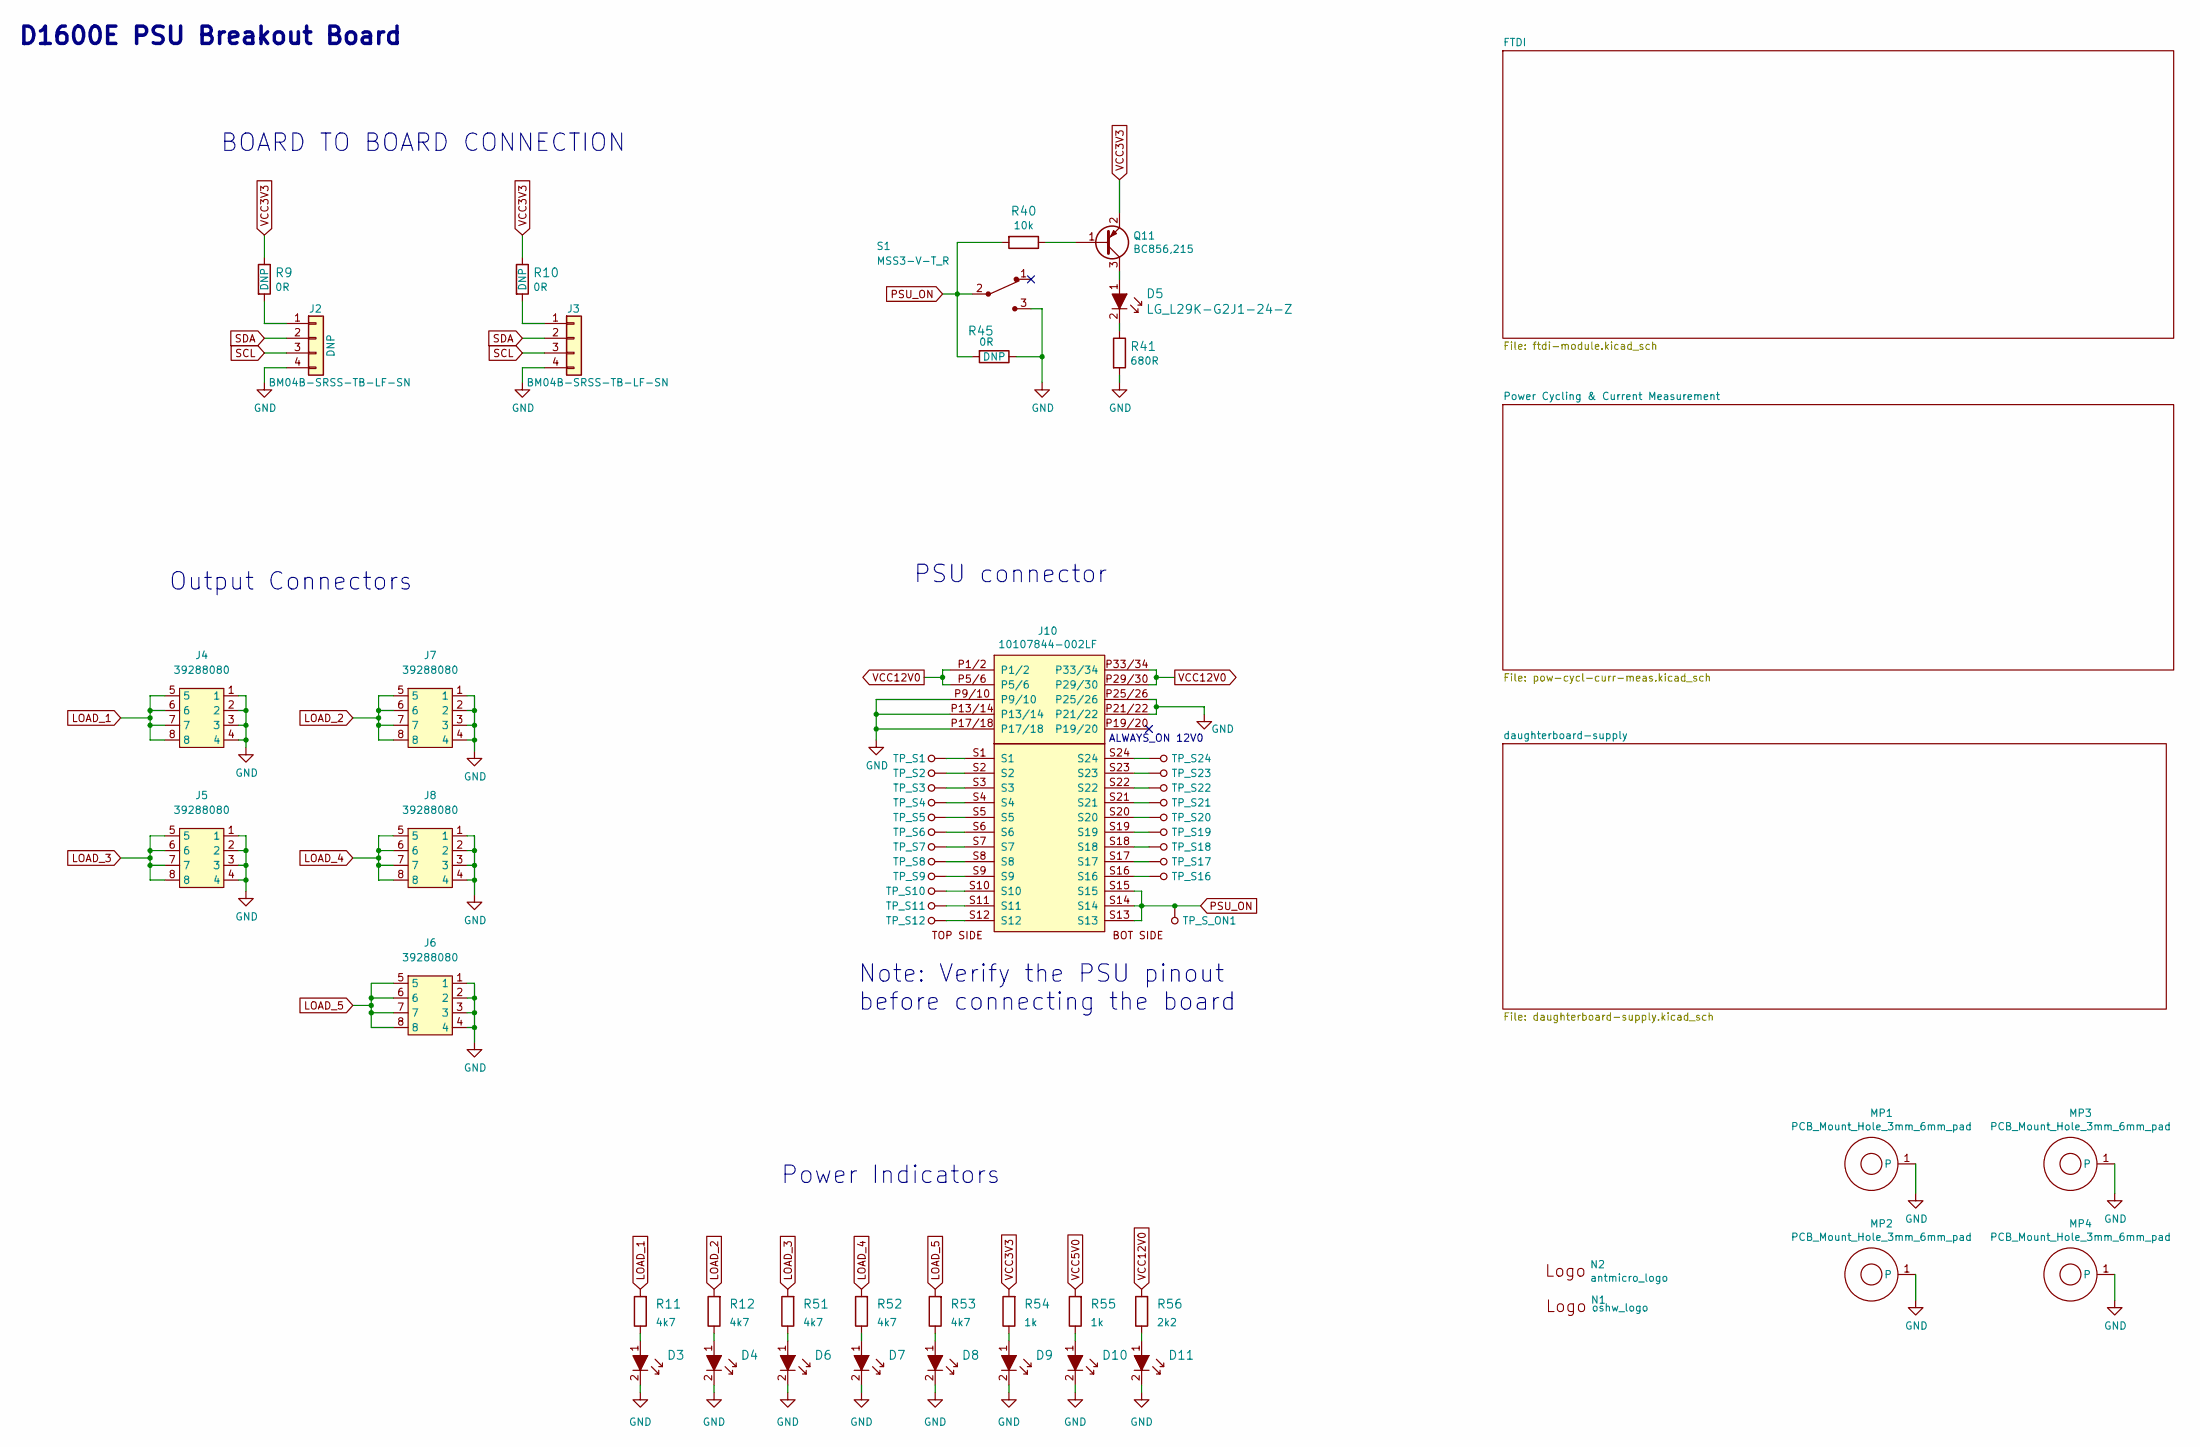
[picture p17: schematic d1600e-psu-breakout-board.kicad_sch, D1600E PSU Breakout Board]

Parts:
D3, D4, D5, D6, D7, D8, D9, D10, D11: LG_L29K-G2J1-24-Z; LED_0603; MPN LG L29K-G2J1-24-Z
J2, J3: BM04B-SRSS-TB-LF-SN; MPN BM04B-SRSS-TB(LF)(SN)
J4, J5, J6, J7, J8: 39288080; MOLEX_39288080; MPN 39288080
J10: 10107844-002LF; MPN 10107844-002LF
MP1, MP2, MP3, MP4: PCB_Mount_Hole_3mm_6mm_pad; mounting-hole-3.2mm
N1: oshw_logo; OSHW-Logo_7.5x8mm_Mask
N2: antmicro_logo; antmicro-logo_scaled_20mm_mask
Q11: BC856,215; SOT-23-3; MPN BC856,215
R9, R10, R45: R_0R_0402; 0402-res; MPN ERJ2GE0R00X
R11, R12, R51, R52, R53: R_4k7_0603; 0603-res; MPN CR0603-FX-4701ELF
R40: R_10k_0402; 0402-res; MPN CRCW040210K0FKEDHP
R41: R_680R_0402; 0402-res; MPN 0402WGJ0681TCE
R54, R55: R_1k_0603; 0603-res; MPN CR0603-JW-102ELF
R56: R_2k2_0603; 0603-res; MPN MCMR06X2201FTL
S1: MSS3-V-T_R; Switch_Slide_MSS3; MPN MSS3-V-T/R
TP_S1, TP_S2, TP_S3, TP_S4, TP_S5, TP_S6, TP_S7, TP_S8, TP_S9, TP_S10, TP_S11, TP_S12, TP_S16, TP_S17, TP_S18, TP_S19, TP_S20, TP_S21, TP_S22, TP_S23, TP_S24: TP_SMD1MM; Testpoint_smd_1mm
TP_S_ON1: TP_SMD1MM; Testpoint_smd_1mm

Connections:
GND: D3.2, D4.2, D6.2, D7.2, D8.2, D9.2, D10.2, D11.2, J2.4, J3.4, J4.1, J4.2, J4.3, J4.4, J5.1, J5.2, J5.3, J5.4, J6.1, J6.2, J6.3, J6.4, J7.1, J7.2, J7.3, J7.4, J8.1, J8.2, J8.3, J8.4, J10.P9/10, J10.P11/12, J10.P13/14, J10.P15/16, J10.P17/18, J10.P21/22, J10.P23/24, J10.P25/26, J10.P27/28, MP1.1, MP2.1, MP3.1, MP4.1, R41.2, R45.1, S1.3; also elsewhere on the board
LOAD_1: J4.5, J4.6, J4.7, J4.8, R11.2; also elsewhere on the board
LOAD_2: J7.5, J7.6, J7.7, J7.8, R12.2; also elsewhere on the board
LOAD_3: J5.5, J5.6, J5.7, J5.8, R51.2; also elsewhere on the board
LOAD_4: J8.5, J8.6, J8.7, J8.8, R52.2; also elsewhere on the board
LOAD_5: J6.5, J6.6, J6.7, J6.8, R53.2; also elsewhere on the board
unnamed: D3.1, R11.1
unnamed: D4.1, R12.1
unnamed: D5.1, Q11.3
unnamed: D5.2, R41.1
unnamed: D6.1, R51.1
unnamed: D7.1, R52.1
unnamed: D8.1, R53.1
unnamed: D9.1, R54.1
unnamed: D10.1, R55.1
unnamed: D11.1, R56.1
unnamed: J2.1, R9.2
unnamed: J3.1, R10.2
unnamed: J10.S1, TP_S1.1
unnamed: J10.S2, TP_S2.1
unnamed: J10.S3, TP_S3.1
unnamed: J10.S4, TP_S4.1
unnamed: J10.S5, TP_S5.1
unnamed: J10.S6, TP_S6.1
unnamed: J10.S7, TP_S7.1
unnamed: J10.S8, TP_S8.1
unnamed: J10.S9, TP_S9.1
unnamed: J10.S10, TP_S10.1
unnamed: J10.S11, TP_S11.1
unnamed: J10.S12, TP_S12.1
unnamed: J10.S16, TP_S16.1
unnamed: J10.S17, TP_S17.1
unnamed: J10.S18, TP_S18.1
unnamed: J10.S19, TP_S19.1
unnamed: J10.S20, TP_S20.1
unnamed: J10.S21, TP_S21.1
unnamed: J10.S22, TP_S22.1
unnamed: J10.S23, TP_S23.1
unnamed: J10.S24, TP_S24.1
unnamed: Q11.1, R40.1
PSU_ON: J10.S13, J10.S14, J10.S15, R40.2, R45.2, S1.2, TP_S_ON1.1
SCL: J2.3, J3.3; also elsewhere on the board
SDA: J2.2, J3.2; also elsewhere on the board
VCC3V3: Q11.2, R9.1, R10.1, R54.2; also elsewhere on the board
VCC12V0: J10.P1/2, J10.P3/4, J10.P5/6, J10.P7/8, J10.P29/30, J10.P31/32, J10.P33/34, J10.P35/36, R56.2; also elsewhere on the board

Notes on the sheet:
PSU connector
Note: Verify the PSU pinout before connecting the board
Power Indicators
ALWAYS_ON 12V0
D1600E PSU Breakout Board
BOARD TO BOARD CONNECTION
Output Connectors

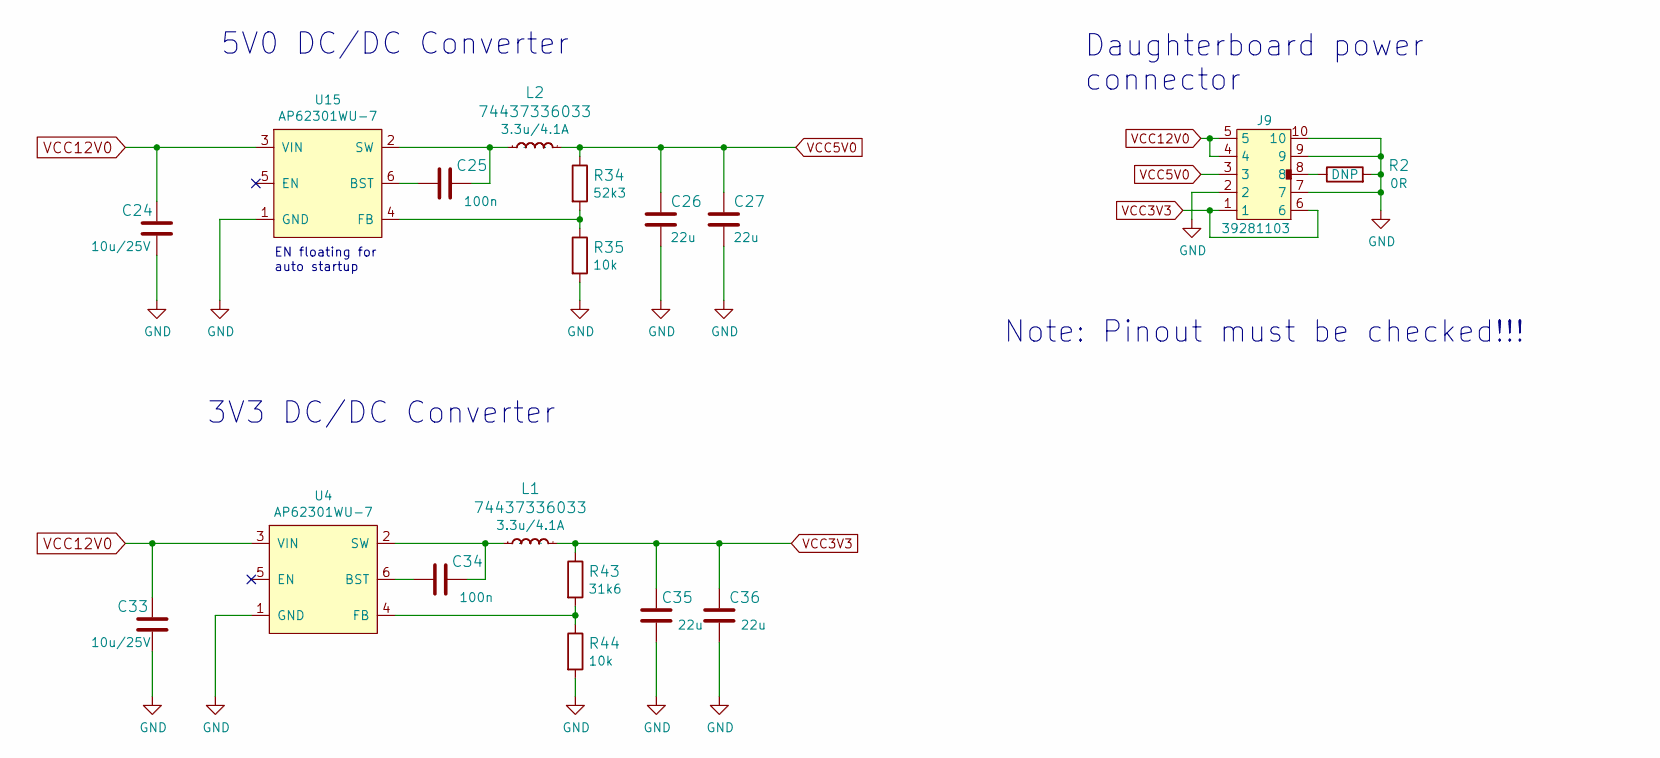
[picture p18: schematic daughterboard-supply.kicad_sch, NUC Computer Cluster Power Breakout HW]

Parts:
C24, C33: C_10u_16V_0603; 0603-cap; MPN C1608X5R1E106M080AC
C25, C34: C_100n_0402; 0402-cap; MPN GRM155R61H104KE14D
C26, C27, C35, C36: C_22u_0603; 0603-cap; MPN GRM188R60J226MEA0D
J9: 39281103; MOLEX_39281103; MPN 39281103
L1, L2: 74437336033; WE_74437336033; MPN 74437336033
R2: R_0R_0402; 0402-res; MPN ERJ2GE0R00X
R34: R_52k3_0402; 0402-res; MPN ERJ-2RKF5232X
R35, R44: R_10k_0402; 0402-res; MPN CRCW040210K0FKEDHP
R43: R_31k6_0402; 0402-res; MPN CRCW040231K6FKEDC
U4, U15: AP62301WU-7; TSOT23-6; MPN AP62301WU-7

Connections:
GND: C24.2, C26.2, C27.2, C33.2, C35.2, C36.2, J9.2, J9.7, J9.9, J9.10, R2.2, R35.2, R44.2, U4.1 (GND), U15.1 (GND); also elsewhere on the board
unnamed: C25.1, L2.1, U15.2 (SW)
unnamed: C25.2, U15.6 (BST)
unnamed: C34.1, L1.1, U4.2 (SW)
unnamed: C34.2, U4.6 (BST)
unnamed: J9.8, R2.1
unnamed: R34.2, R35.1, U15.4 (FB)
unnamed: R43.2, R44.1, U4.4 (FB)
VCC3V3: C35.1, C36.1, J9.1, J9.6, L1.2, R43.1; also elsewhere on the board
VCC5V0: C26.1, C27.1, J9.3, L2.2, R34.1
VCC12V0: C24.1, C33.1, J9.4, J9.5, U4.3 (VIN), U15.3 (VIN); also elsewhere on the board

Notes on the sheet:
5V0 DC/DC Converter
Daughterboard power connector
3V3 DC/DC Converter
EN floating for auto startup
Note: Pinout must be checked!!!

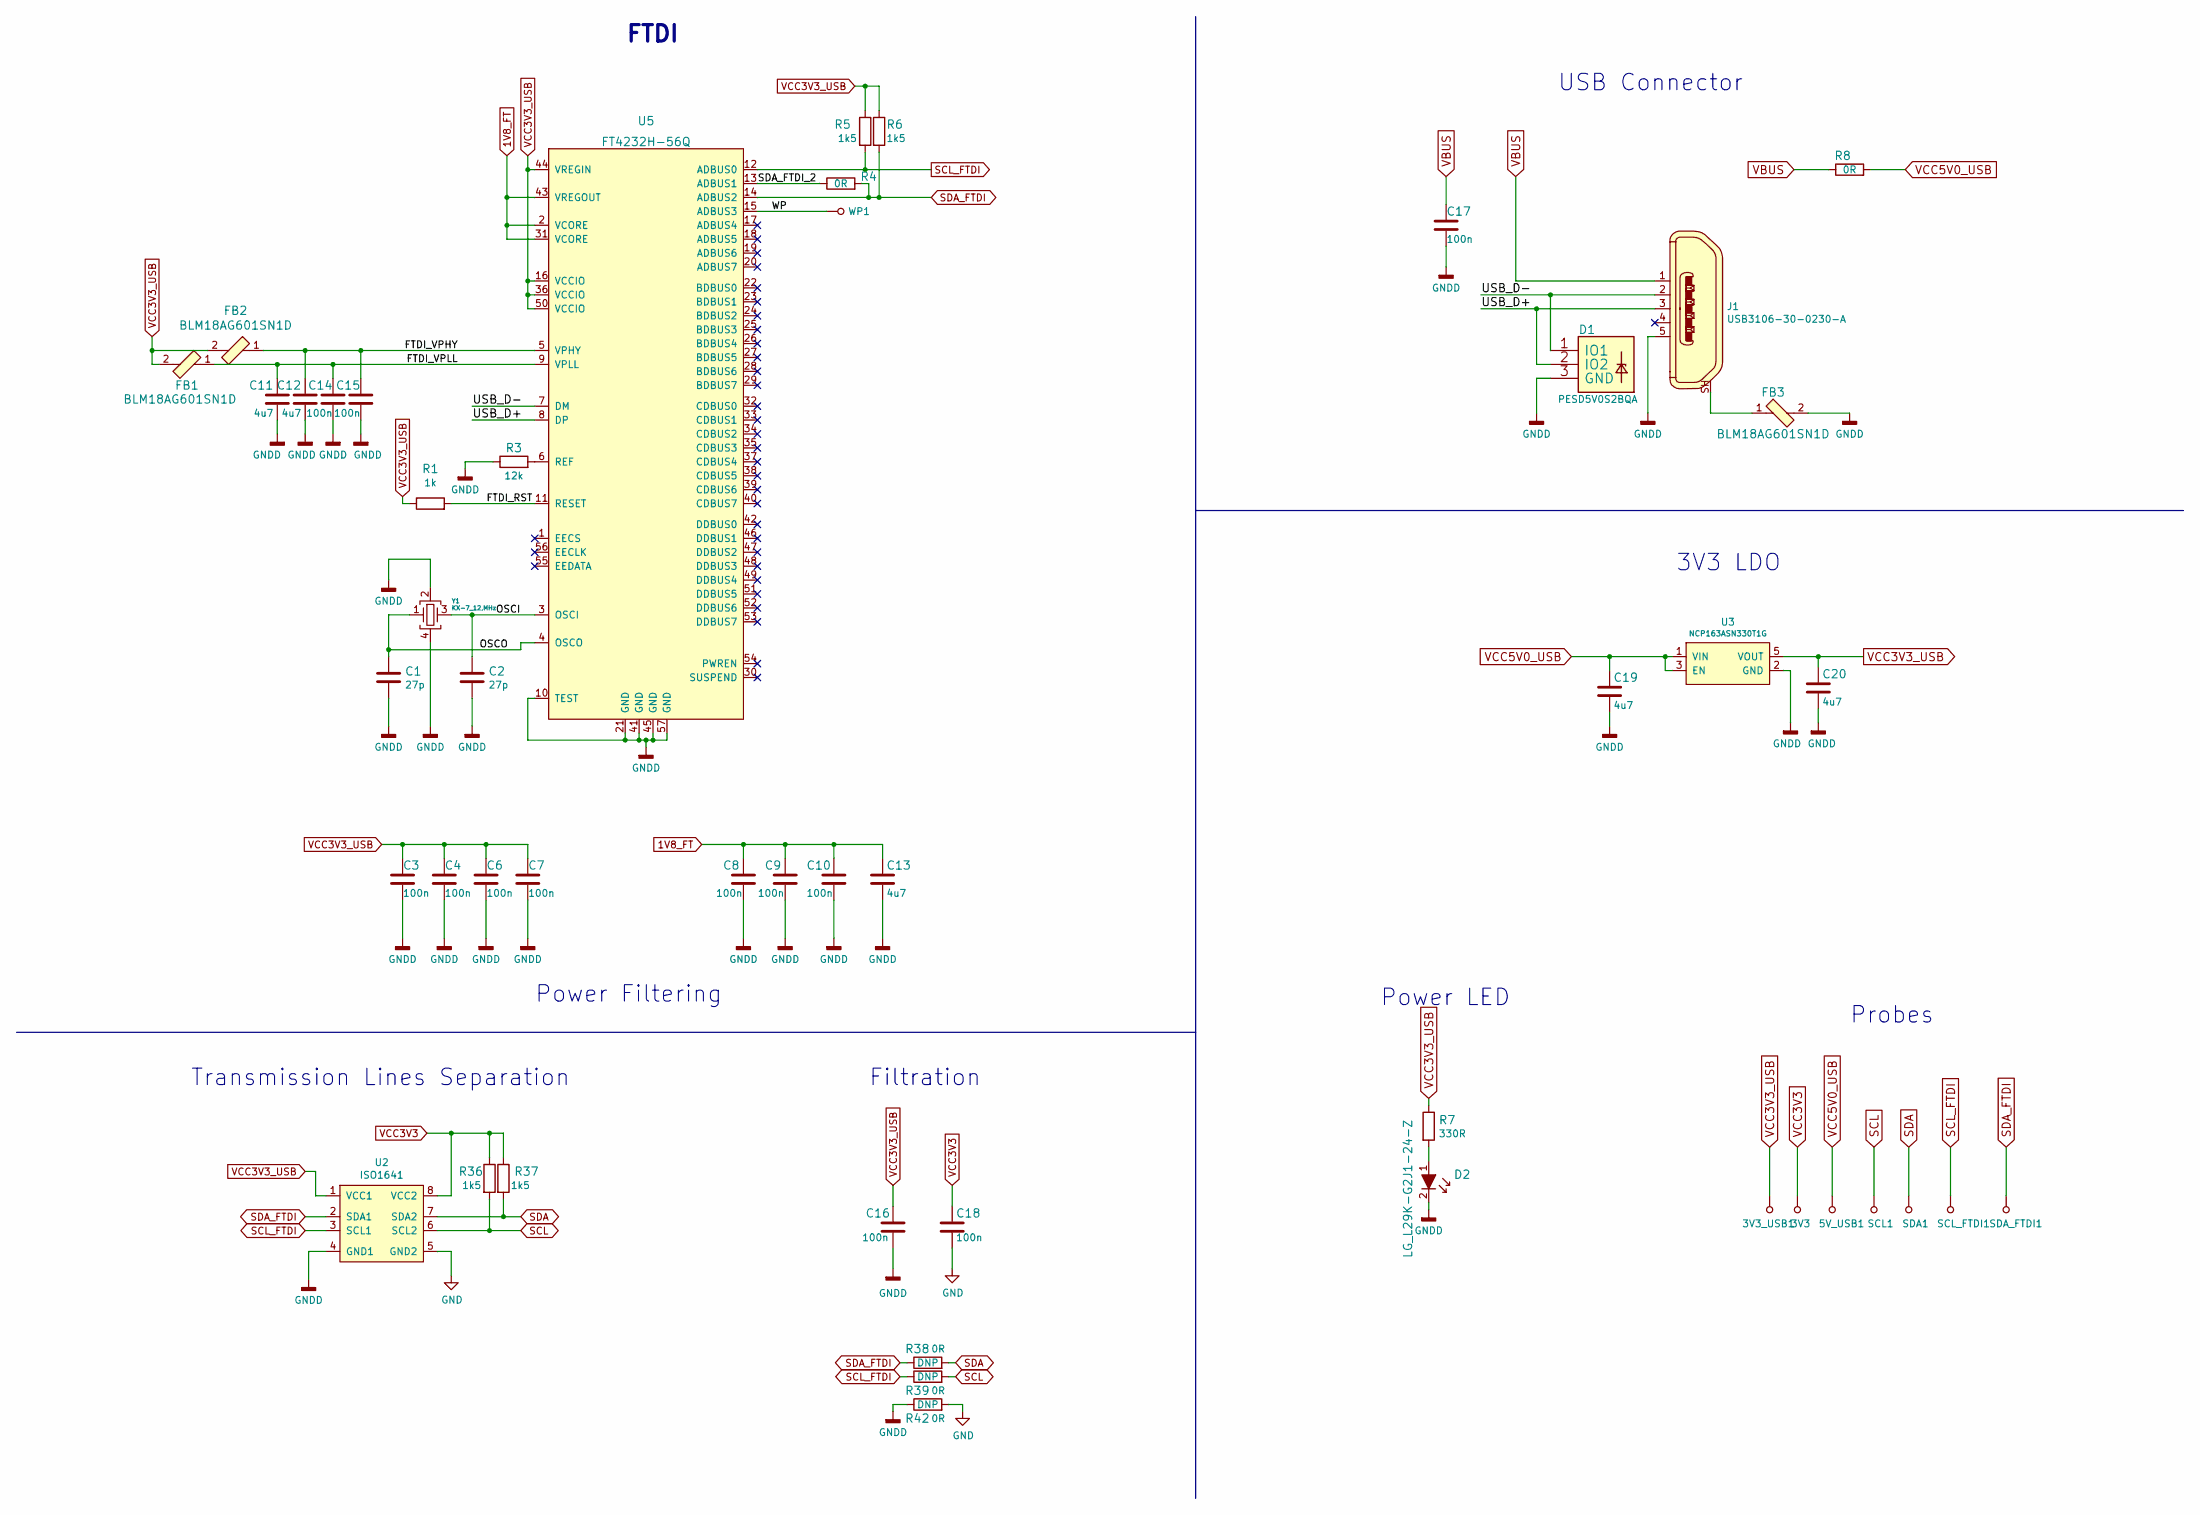
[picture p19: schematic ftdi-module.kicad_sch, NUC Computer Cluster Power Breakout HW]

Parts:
3V3, 3V3_USB1, 5V_USB1: TP_SMD1MM; Testpoint_smd_1mm
C1, C2: C_27p_0402; 0402-cap; MPN 0402N270J500CT
C3, C4, C6, C7, C8, C9, C10, C14, C15, C16, C17, C18: C_100n_0402; 0402-cap; MPN GRM155R61H104KE14D
C11, C12, C13, C19, C20: C_4u7_0402; 0402-cap; MPN GRM155R61A475MEAAD
D1: PESD5V0S2BQA; TPD2E009DRTR; MPN PESD5V0S2BQA
D2: LG_L29K-G2J1-24-Z; LED_0603; MPN LG L29K-G2J1-24-Z
FB1, FB2, FB3: BLM18AG601SN1D; 0603; MPN BLM18AG601SN1D
J1: USB3106-30-0230-A; usb3106-30-0230; MPN USB3106-30-0230-A
R1: R_1k_0402; 0402-res; MPN CR0402-FX-1001GLF
R3: R_12k_0402; 0402-res; MPN CRCW040212K0FKEDHP
R4, R8, R38, R39, R42: R_0R_0603; 0603-res; MPN CR0603-J/-000ELF
R5, R6, R36, R37: R_1k5_0402; 0402-res; MPN MP000515
R7: R_330R_0402; 0402-res; MPN MCMR04X3300FTL
SCL1: TP_SMD1MM; Testpoint_smd_1mm
SCL_FTDI1: TP_SMD1MM; Testpoint_smd_1mm
SDA1: TP_SMD1MM; Testpoint_smd_1mm
SDA_FTDI1: TP_SMD1MM; Testpoint_smd_1mm
U2: ISO1641; SOIC-8_W3.9mm; MPN ISO1641BDR
U3: NCP163ASN330T1G; SOT-23-5; MPN NCP163ASN330T1G
U5: FT4232H-56Q; QFN-56-1EP_8x8mm_P0.5mm_EP5.5.9x5.9mm; MPN FT4232H-56Q-REEL
WP1: TP_SMD1MM; Testpoint_smd_1mm
Y1: KX-7_12,MHz; KX-7; MPN KX-7_SMD_CRYSTAL_12,0 MHZ

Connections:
1V8_FT: C8.1, C9.1, C10.1, C13.1, U5.2 (VCORE), U5.31 (VCORE), U5.43 (VREGOUT)
/FTDI/FTDI_RST: R1.2, U5.11 (RESET)
/FTDI/FTDI_VPHY: C12.1, C15.1, FB2.1, U5.5 (VPHY)
/FTDI/FTDI_VPLL: C11.1, C14.1, FB1.1, U5.9 (VPLL)
/FTDI/OSCI: C2.1, U5.3 (OSCI), Y1.3
/FTDI/OSCO: C1.1, U5.4 (OSCO), Y1.1
/FTDI/SDA_FTDI_2: R4.1, U5.13 (ADBUS1)
/FTDI/USB_D+: D1.2 (IO2), J1.3, U5.8 (DP)
/FTDI/USB_D-: D1.1 (IO1), J1.2, U5.7 (DM)
/FTDI/WP: U5.15 (ADBUS3), WP1.1
GND: C18.2, R42.2, U2.5 (GND2); also elsewhere on the board
GNDD: C1.2, C2.2, C3.2, C4.2, C6.2, C7.2, C8.2, C9.2, C10.2, C11.2, C12.2, C13.2, C14.2, C15.2, C16.2, C17.2, C19.2, C20.2, D1.3 (GND), D2.2, FB3.2, J1.5, R3.1, R42.1, U2.4 (GND1), U3.2 (GND), U5.10 (TEST), U5.21 (GND), U5.41 (GND), U5.45 (GND), U5.57 (GND), Y1.2, Y1.4
unnamed: D2.1, R7.2
unnamed: FB3.1, J1.SH
unnamed: R3.2, U5.6 (REF)
SCL: R36.2, R39.2, SCL1.1, U2.6 (SCL2); also elsewhere on the board
SCL_FTDI: R5.2, R39.1, SCL_FTDI1.1, U2.3 (SCL1), U5.12 (ADBUS0)
SDA: R37.2, R38.2, SDA1.1, U2.7 (SDA2); also elsewhere on the board
SDA_FTDI: R4.2, R6.2, R38.1, SDA_FTDI1.1, U2.2 (SDA1), U5.14 (ADBUS2)
VBUS: C17.1, J1.1, R8.1
VCC3V3: 3V3.1, C18.1, R36.1, R37.1, U2.8 (VCC2); also elsewhere on the board
VCC3V3_USB: 3V3_USB1.1, C3.1, C4.1, C6.1, C7.1, C16.1, C20.1, FB1.2, FB2.2, R1.1, R5.1, R6.1, R7.1, U2.1 (VCC1), U3.5 (VOUT), U5.16 (VCCIO), U5.36 (VCCIO), U5.44 (VREGIN), U5.50 (VCCIO)
VCC5V0_USB: 5V_USB1.1, C19.1, R8.2, U3.1 (VIN), U3.3 (EN)

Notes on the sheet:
FTDI
Power Filtering
USB Connector
Transmission Lines Separation
Probes
Filtration
Power LED
3V3 LDO

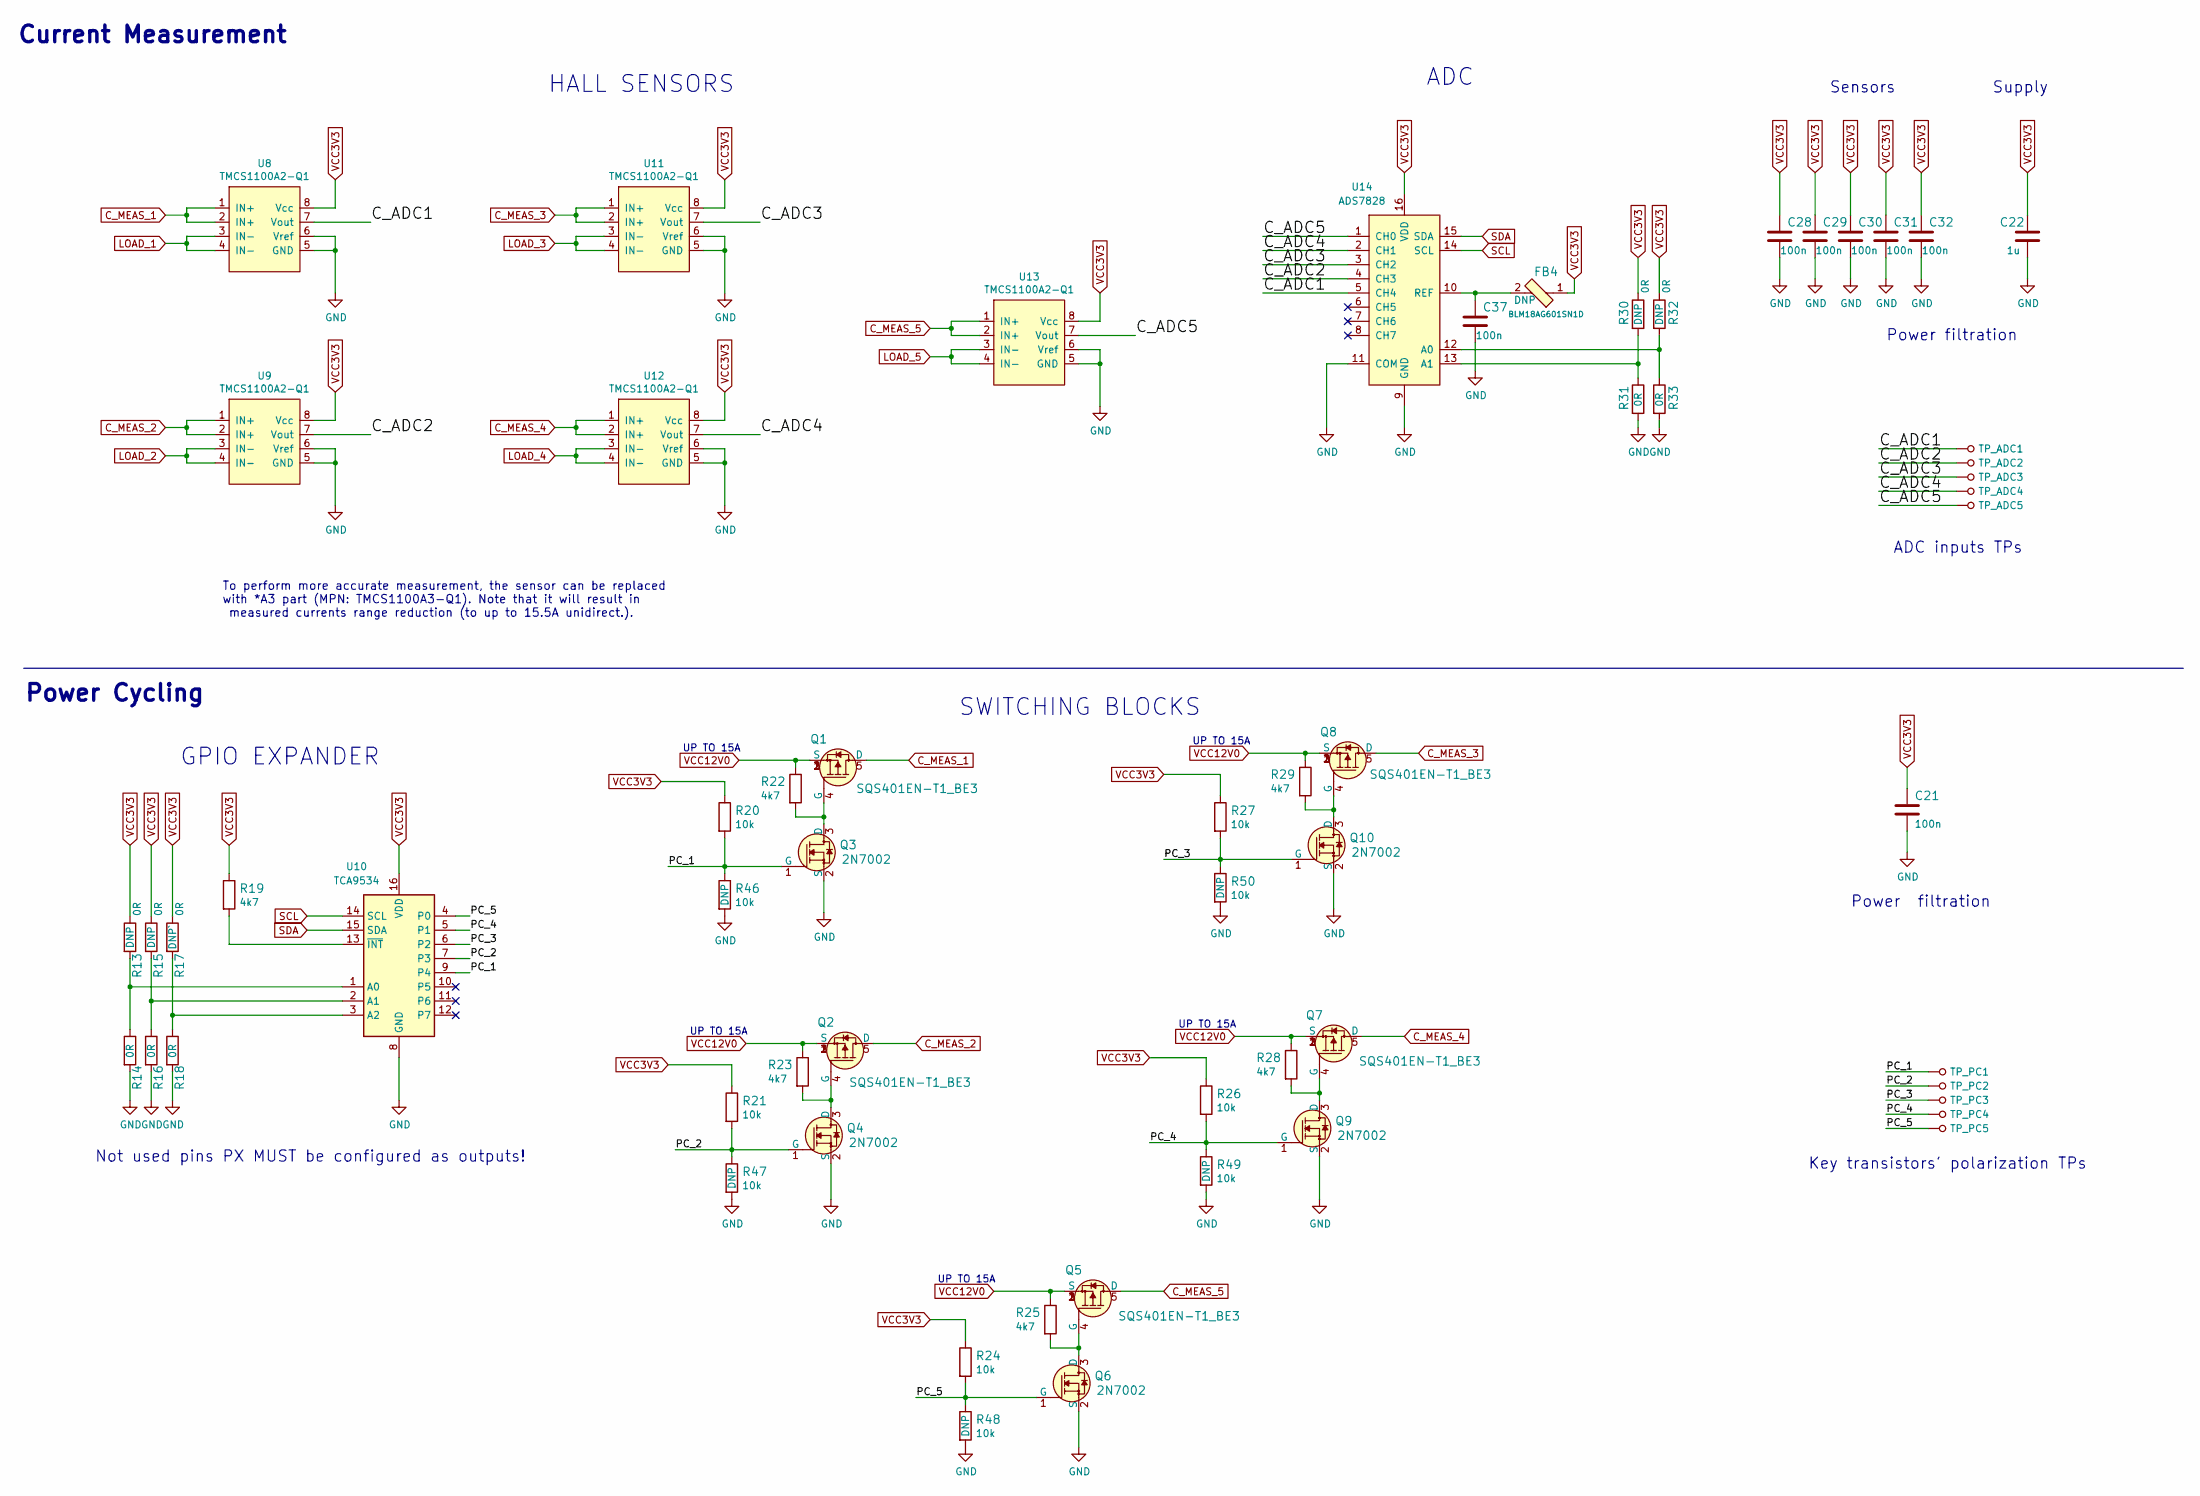
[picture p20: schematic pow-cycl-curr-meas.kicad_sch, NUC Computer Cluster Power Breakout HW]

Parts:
C21, C28, C29, C30, C31, C32, C37: C_100n_0402; 0402-cap; MPN GRM155R61H104KE14D
C22: C_1u_0402; 0402-cap; MPN C1005X6S1A105K050BC
FB4: BLM18AG601SN1D; 0603; MPN BLM18AG601SN1D
Q1, Q2, Q5, Q7, Q8: SQS401EN-T1_BE3; Vishay_PowerPAK_1212-8_Single; MPN SQS401EN-T1_BE3
Q3, Q4, Q6, Q9, Q10: 2N7002; SOT-23-3; MPN 2N7002
R13, R14, R15, R16, R17, R18, R30, R31, R32, R33: R_0R_0402; 0402-res; MPN ERJ2GE0R00X
R19, R22, R23, R25, R28, R29: R_4k7_0402; 0402-res; MPN MCS04020C4701FE000
R20, R21, R24, R26, R27, R46, R47, R48, R49, R50: R_10k_0402; 0402-res; MPN CRCW040210K0FKEDHP
TP_ADC1, TP_ADC2, TP_ADC3, TP_ADC4, TP_ADC5: TP_SMD1MM; Testpoint_smd_1mm
TP_PC1, TP_PC2, TP_PC3, TP_PC4, TP_PC5: TP_SMD1MM; Testpoint_smd_1mm
U8, U9, U11, U12, U13: TMCS1100A2-Q1; SOIC-8_W3.9mm; MPN TMCS1100A2QDRQ1
U10: TCA9534; TSSOP-16; MPN TCA9534ADWR
U14: ADS7828; TSSOP-16_4.4x5mm_P0.65mm; MPN ADS7828E/250

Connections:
/Power Cycling & Current Measurement/C_ADC1: TP_ADC1.1, U8.7 (Vout), U14.5 (CH4)
/Power Cycling & Current Measurement/C_ADC2: TP_ADC2.1, U9.7 (Vout), U14.4 (CH3)
/Power Cycling & Current Measurement/C_ADC3: TP_ADC3.1, U11.7 (Vout), U14.3 (CH2)
/Power Cycling & Current Measurement/C_ADC4: TP_ADC4.1, U12.7 (Vout), U14.2 (CH1)
/Power Cycling & Current Measurement/C_ADC5: TP_ADC5.1, U13.7 (Vout), U14.1 (CH0)
/Power Cycling & Current Measurement/PC_1: Q3.1 (G), R20.2, R46.1, TP_PC1.1, U10.9 (P4)
/Power Cycling & Current Measurement/PC_2: Q4.1 (G), R21.2, R47.1, TP_PC2.1, U10.7 (P3)
/Power Cycling & Current Measurement/PC_3: Q10.1 (G), R27.2, R50.1, TP_PC3.1, U10.6 (P2)
/Power Cycling & Current Measurement/PC_4: Q9.1 (G), R26.2, R49.1, TP_PC4.1, U10.5 (P1)
/Power Cycling & Current Measurement/PC_5: Q6.1 (G), R24.2, R48.1, TP_PC5.1, U10.4 (P0)
C_MEAS_1: Q1.5 (D), U8.1 (IN+), U8.2 (IN+)
C_MEAS_2: Q2.5 (D), U9.1 (IN+), U9.2 (IN+)
C_MEAS_3: Q8.5 (D), U11.1 (IN+), U11.2 (IN+)
C_MEAS_4: Q7.5 (D), U12.1 (IN+), U12.2 (IN+)
C_MEAS_5: Q5.5 (D), U13.1 (IN+), U13.2 (IN+)
GND: C21.2, C22.2, C28.2, C29.2, C30.2, C31.2, C32.2, C37.2, Q3.2 (S), Q4.2 (S), Q6.2 (S), Q9.2 (S), Q10.2 (S), R14.2, R16.2, R18.2, R31.2, R33.2, R46.2, R47.2, R48.2, R49.2, R50.2, U8.5 (GND), U8.6 (Vref), U9.5 (GND), U9.6 (Vref), U10.8 (GND), U11.5 (GND), U11.6 (Vref), U12.5 (GND), U12.6 (Vref), U13.5 (GND), U13.6 (Vref), U14.9 (GND), U14.11 (COM); also elsewhere on the board
LOAD_1: U8.3 (IN-), U8.4 (IN-); also elsewhere on the board
LOAD_2: U9.3 (IN-), U9.4 (IN-); also elsewhere on the board
LOAD_3: U11.3 (IN-), U11.4 (IN-); also elsewhere on the board
LOAD_4: U12.3 (IN-), U12.4 (IN-); also elsewhere on the board
LOAD_5: U13.3 (IN-), U13.4 (IN-); also elsewhere on the board
unnamed: C37.1, FB4.2, U14.10 (REF)
unnamed: Q1.4 (G), Q3.3 (D), R22.2
unnamed: Q2.4 (G), Q4.3 (D), R23.2
unnamed: Q5.4 (G), Q6.3 (D), R25.2
unnamed: Q7.4 (G), Q9.3 (D), R28.2
unnamed: Q8.4 (G), Q10.3 (D), R29.2
unnamed: R13.2, R14.1, U10.1 (A0)
unnamed: R15.2, R16.1, U10.2 (A1)
unnamed: R17.2, R18.1, U10.3 (A2)
unnamed: R19.2, U10.13 (~INT)
unnamed: R30.2, R31.1, U14.13 (A1)
unnamed: R32.2, R33.1, U14.12 (A0)
SCL: U10.14 (SCL), U14.14 (SCL); also elsewhere on the board
SDA: U10.15 (SDA), U14.15 (SDA); also elsewhere on the board
VCC3V3: C21.1, C22.1, C28.1, C29.1, C30.1, C31.1, C32.1, FB4.1, R13.1, R15.1, R17.1, R19.1, R20.1, R21.1, R24.1, R26.1, R27.1, R30.1, R32.1, U8.8 (Vcc), U9.8 (Vcc), U10.16 (VDD), U11.8 (Vcc), U12.8 (Vcc), U13.8 (Vcc), U14.16 (VDD); also elsewhere on the board
VCC12V0: Q1.1 (S), Q1.2 (S), Q1.3 (S), Q2.1 (S), Q2.2 (S), Q2.3 (S), Q5.1 (S), Q5.2 (S), Q5.3 (S), Q7.1 (S), Q7.2 (S), Q7.3 (S), Q8.1 (S), Q8.2 (S), Q8.3 (S), R22.1, R23.1, R25.1, R28.1, R29.1; also elsewhere on the board

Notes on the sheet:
Not used pins PX MUST be configured as outputs!
Current Measurement
ADC inputs TPs
SWITCHING BLOCKS
Key transistors' polarization TPs
ADC
UP TO 15A
GPIO EXPANDER
To perform more accurate measurement, the sensor can be replaced with *A3 part (MPN: TMCS1100A3-Q1). Note that it will result in measured currents range reduction (to up to 15.5A unidirect.).
HALL SENSORS
Power filtration
Sensors
Supply
Power filtration
Power Cycling

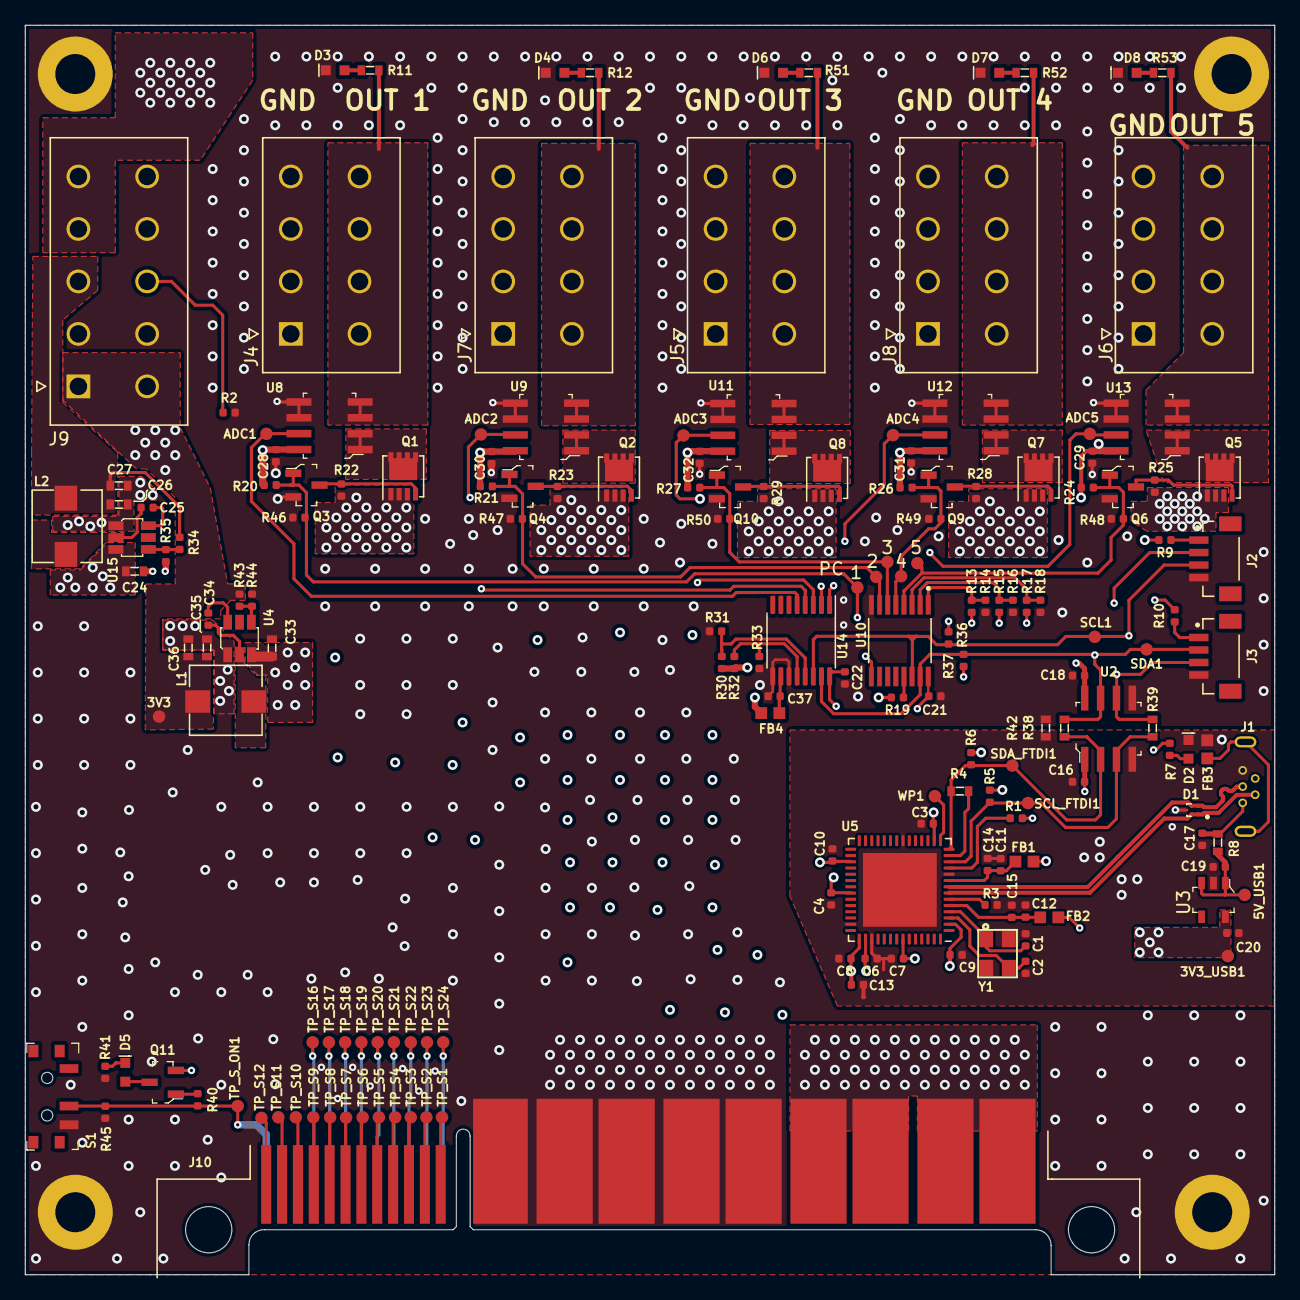
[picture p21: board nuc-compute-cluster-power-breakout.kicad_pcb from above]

Board: 4 copper layers, 100.0 x 100.0 mm, 183 parts (0 on the bottom side), 96 nets.

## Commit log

2022-03-03 Initial commit - KiCAD project
    [nuc-compute-cluster-power-breakout-hw.kicad_pcb, nuc-compute-cluster-power-breakout-hw.sch]
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2022-03-07 Small improvements. Power cycling module sheet
    [ftdi-module.sch, nuc-compute-cluster-power-breakout-hw.sch, pow-cycl-curr-meas.sch]
2022-03-08 Power cycling module improvement
    [pow-cycl-curr-meas.sch]
2022-03-11 Power cycling module update
    [pow-cycl-curr-meas.sch]
2022-03-11 Logic Shifter Module. Current Meas. implementation
    [ftdi-module.sch, pow-cycl-curr-meas.sch]
2022-03-14 Current Module upgrade. Logic unification.
    [ftdi-module.sch, pow-cycl-curr-meas.sch]
2022-03-15 Added connection between breakout boards
    [ftdi-module.sch, nuc-compute-cluster-power-breakout-hw.sch, pow-cycl-curr-meas.sch]
2022-03-17 Schematic improvements according to review's comments
    [ftdi-module.sch, nuc-compute-cluster-power-breakout-hw.sch, nuc-compute-cluster-power-breakout.kicad_pcb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]
2022-03-18 Change schematic sheet's name
    [daughterboard-supply.sch, nuc-compute-cluster-power-breakout.sch]
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2022-09-29 Added power distribution connectors
    [daughterboard-supply.sch, nuc-compute-cluster-power-breakout.sch]
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2022-09-29 PCB creation. Components gathered in functional groups
    [daughterboard-supply.sch, ftdi-module.sch, nuc-compute-cluster-power-breakout.kicad_pcb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]
2022-09-29 Initial component placement done
    [ftdi-module.sch, nuc-compute-cluster-power-breakout.kicad_pcb, pow-cycl-curr-meas.sch]
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2022-09-29 Initial routing. Small schematics improvements
    [ftdi-module.sch, nuc-compute-cluster-power-breakout.kicad_pcb, pow-cycl-curr-meas.sch]
2022-09-29 Routing and power planes
    [nuc-compute-cluster-power-breakout.kicad_pcb]
2022-09-29 First revision of PCB finished
    [ftdi-module.sch, nuc-compute-cluster-power-breakout.kicad_pcb, pow-cycl-curr-meas.sch]
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2022-09-29 Add remarks on the schematic sheets
    [daughterboard-supply.sch, ftdi-module.sch, nuc-compute-cluster-power-breakout.sch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]
2022-09-29 Add remarks to the PCB file
    [nuc-compute-cluster-power-breakout.kicad_pcb]
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2022-09-29 Added switch for daughterboard's supply
    [daughterboard-supply.sch]
2022-09-29 Added PSU power on switch
    [nuc-compute-cluster-power-breakout.sch]
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2022-09-29 Replaced +3V3 with GND plane
    [nuc-compute-cluster-power-breakout.kicad_pcb]
2022-09-29 FTDI layout redesign
    [daughterboard-supply.sch, nuc-compute-cluster-power-breakout.kicad_pcb, nuc-compute-cluster-power-breakout.sch]
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2022-09-29 Added power switch. PCB update.
    [nuc-compute-cluster-power-breakout.kicad_pcb, nuc-compute-cluster-power-breakout.sch]
2022-09-29 Added stitching and mounting holes
    [nuc-compute-cluster-power-breakout.kicad_pcb, nuc-compute-cluster-power-breakout.sch]
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2022-09-29 Add remarks to the schematic
    [ftdi-module.sch, nuc-compute-cluster-power-breakout.sch]
2022-09-29 Adjust the power plane distribution
    [nuc-compute-cluster-power-breakout.kicad_pcb]
2022-09-29 Added mising GND to schematic
    [nuc-compute-cluster-power-breakout.sch]
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2022-09-29 Patches after 2nd revision
    [nuc-compute-cluster-power-breakout.kicad_pcb, nuc-compute-cluster-power-breakout.sch, pow-cycl-curr-meas.sch]
2022-09-29 NUC's connector moved. Mounting holes repositioning
    [nuc-compute-cluster-power-breakout.kicad_pcb]
2022-09-29 Eliminated DRC errors
    [nuc-compute-cluster-power-breakout.kicad_pcb]
2022-09-29 Added board cut-out. Logos replacement
    [nuc-compute-cluster-power-breakout.kicad_pcb, nuc-compute-cluster-power-breakout.sch]
2022-09-29 Change the board name
    [nuc-compute-cluster-power-breakout.kicad_pcb]
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2022-09-29 Initial galvanic isolation added to layout
    [nuc-compute-cluster-power-breakout.kicad_pcb]
2022-09-29 Complete galvanic isolated layout
    [ftdi-module.sch, nuc-compute-cluster-power-breakout.kicad_pcb]
2022-09-29 Label output channel names
    [nuc-compute-cluster-power-breakout.kicad_pcb]
2022-09-29 Add R45 to implement ALWAYS ON feature
    [nuc-compute-cluster-power-breakout.kicad_pcb, nuc-compute-cluster-power-breakout.sch]
2022-09-29 Resolve annular ring DRC issues
    [nuc-compute-cluster-power-breakout.kicad_pcb]
2022-09-29 Remove soldermask from Molex connectors, Increased pad sizes for Molex connectors
    [nuc-compute-cluster-power-breakout.kicad_pcb]
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2022-09-29 Switching transistor bug fix
    [pow-cycl-curr-meas.sch]
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2022-09-29 Transistors orientation fix
    [nuc-compute-cluster-power-breakout.kicad_pcb]
2022-09-29 Fixed swapped I2C lines Corrected silkscreen layer Rearranged EdgeConn test points
    [ftdi-module.sch, nuc-compute-cluster-power-breakout.kicad_pcb]
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2022-09-29 Fixed FTDI sheet
    [daughterboard-supply.kicad_sch, ftdi-module.kicad_sch, nuc-compute-cluster-power-breakout.kicad_sch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]
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2022-09-29 Finished layout and fixed silkscreen
    [nuc-compute-cluster-power-breakout.kicad_pcb]
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2022-09-29 Added support for default off and changed converter cap voltage rating
    [daughterboard-supply.kicad_sch, ftdi-module.kicad_sch, nuc-compute-cluster-power-breakout.kicad_pcb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]
2022-09-29 Replaced FTDI chip with FT4232H-56Q on the schematic
    [daughterboard-supply.kicad_sch, ftdi-module.kicad_sch, nuc-compute-cluster-power-breakout.kicad_pcb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]
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2022-09-29 Replaced transistors with larger package
    [nuc-compute-cluster-power-breakout.kicad_pcb, nuc-compute-cluster-power-breakout.kicad_sch, pow-cycl-curr-meas.kicad_sch]
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2022-09-29 Add photo, unify the size of schematic sheets
    [daughterboard-supply.kicad_sch, ftdi-module.kicad_sch, nuc-compute-cluster-power-breakout.kicad_sch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]
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2022-12-13 Replaced usb micro to USB C
    [d1600e-psu-breakout-board.kicad_sch, ftdi-module.kicad_sch]
2022-12-13 Added protection for I2C, fix resistor value for USB C, Fixed J9 reversed polarity, minor width fix to 3v3 line
    [d1600e-psu-breakout-board.kicad_sch, daughterboard-supply.kicad_sch, ftdi-module.kicad_sch]
2022-12-15 Aded molex connectors for PCI-e risers and pul up down option for 5V info rail from coordinator
    [d1600e-psu-breakout-board.kicad_sch, daughterboard-supply.kicad_sch]
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2022-12-21 Added all changes proposed in first review of the board
    [d1600e-psu-breakout-board.kicad_sch, daughterboard-supply.kicad_sch, ftdi-module.kicad_sch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]
2022-12-22 Fixed USB tracks,VBUS&GNDD, DRC errors and warning, added protection zener diodes
    [d1600e-psu-breakout-board.kicad_sch, pow-cycl-curr-meas.kicad_sch]
2022-12-22 Changed revision version and date on board and schematic
    [d1600e-psu-breakout-board.kicad_sch, daughterboard-supply.kicad_sch, ftdi-module.kicad_sch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]
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2023-02-08 Fixed IO expander MPN
    [pow-cycl-curr-meas.kicad_sch]
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2023-10-18 #50436 Add FTDI led control, bump revision to 1.4.2
    [d1600e-psu-breakout-board.kicad_sch, daughterboard-supply.kicad_sch, ftdi-module.kicad_sch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]
2023-10-18 #50436 Set U2 as DNP, add assembly variant table, bump to 1.4.3
    [d1600e-psu-breakout-board.kicad_sch, daughterboard-supply.kicad_sch, ftdi-module.kicad_sch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]
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

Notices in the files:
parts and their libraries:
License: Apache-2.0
